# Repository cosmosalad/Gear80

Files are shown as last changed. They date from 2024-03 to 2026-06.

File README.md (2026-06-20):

[▶ Check Out GearSeries](https://github.com/cosmosalad/GearSeries)<br/>
[자작 과정(kr)](https://blog.naver.com/cosmosalad/223262540878)<br/><br/>

# Gear80<br/>
Gear80 is a 80% keyboard based on the rp2040.

<br/>

- gear80_wkl_Aluminum (CNC, Bead blasting-100 mesh + Anodizing-Black-Matte)

<p align="center">
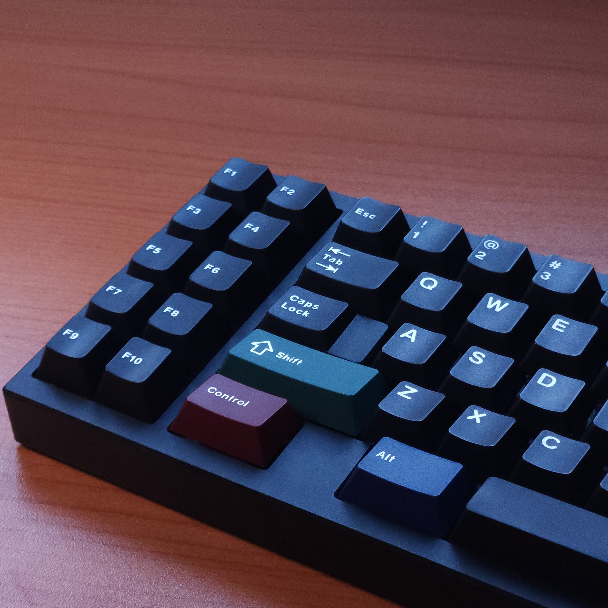
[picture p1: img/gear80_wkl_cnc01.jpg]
    
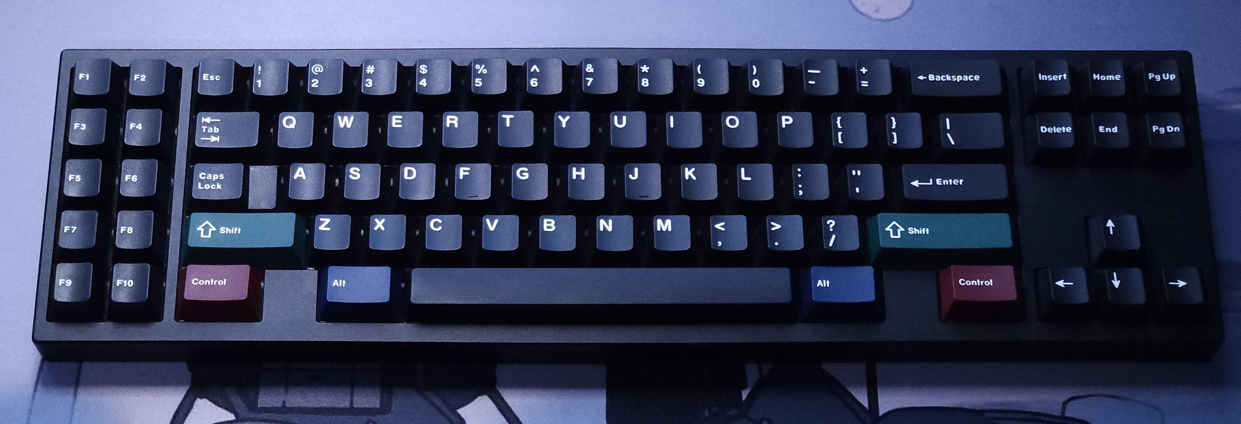
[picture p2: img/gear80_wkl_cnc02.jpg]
  

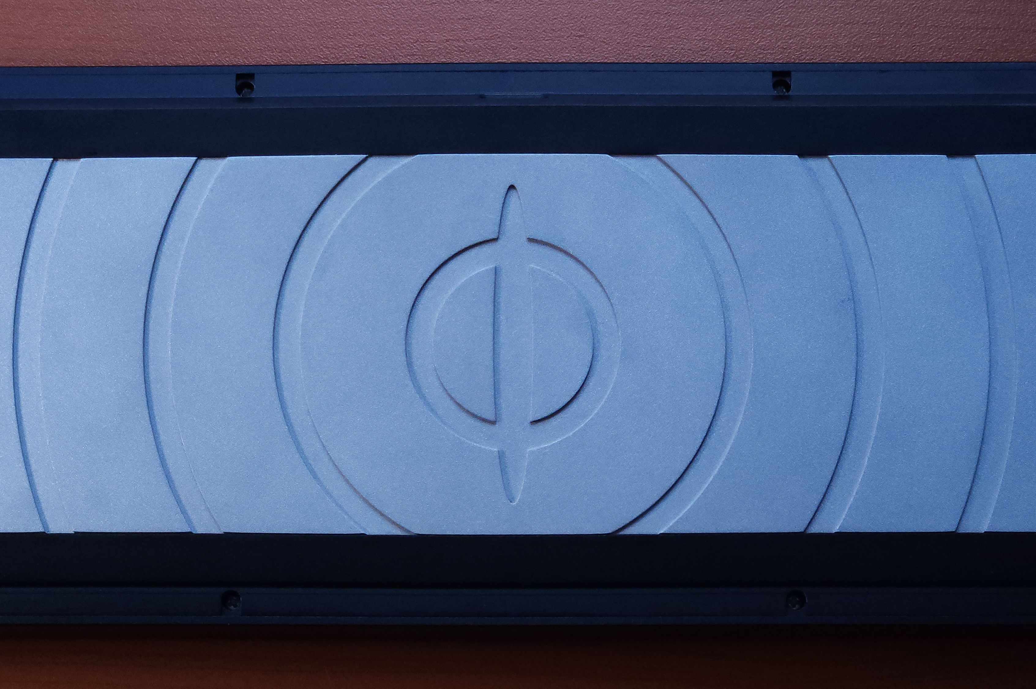
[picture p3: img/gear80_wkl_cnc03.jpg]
    
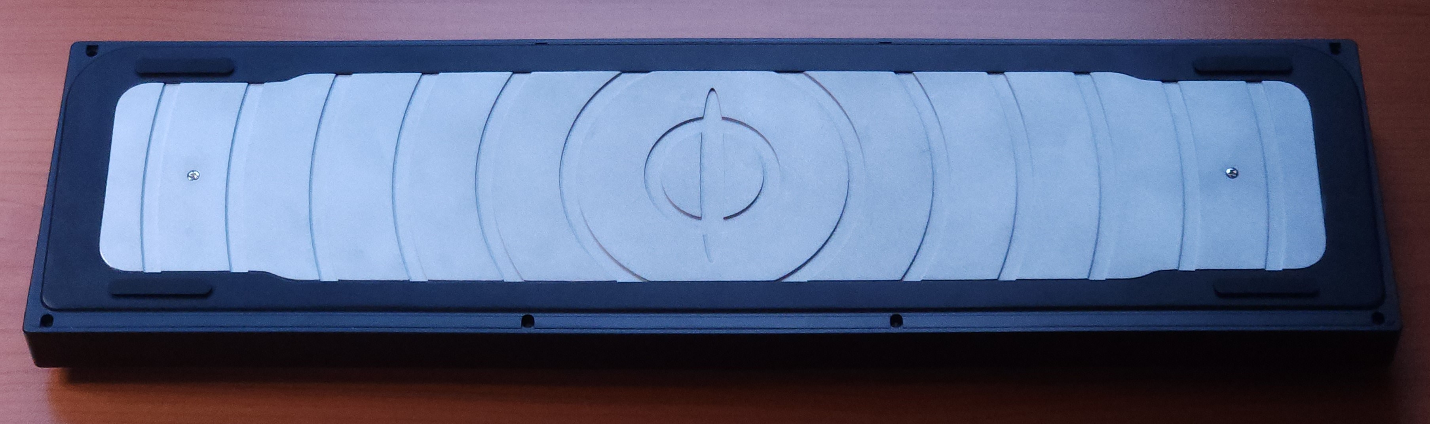
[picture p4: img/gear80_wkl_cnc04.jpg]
  

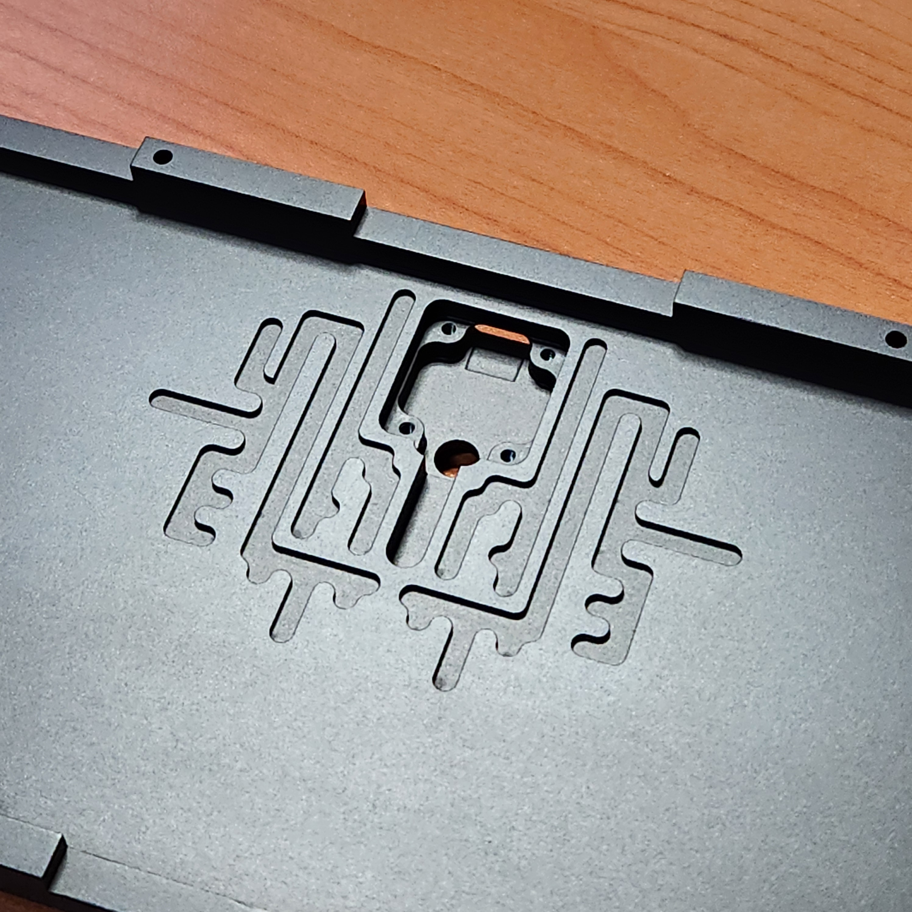
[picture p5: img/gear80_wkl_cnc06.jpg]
    
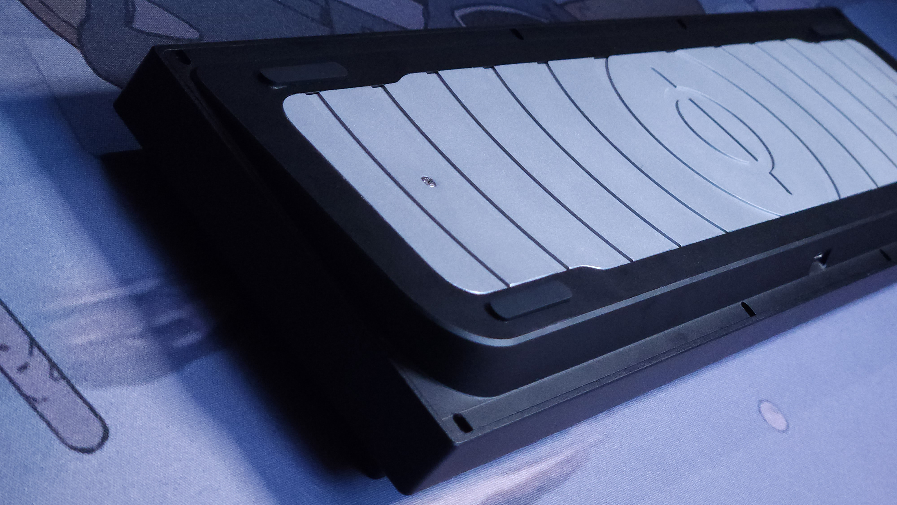
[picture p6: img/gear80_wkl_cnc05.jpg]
  
</p>

<br/>

- gear80_wkl (sla print)

<p align="center">
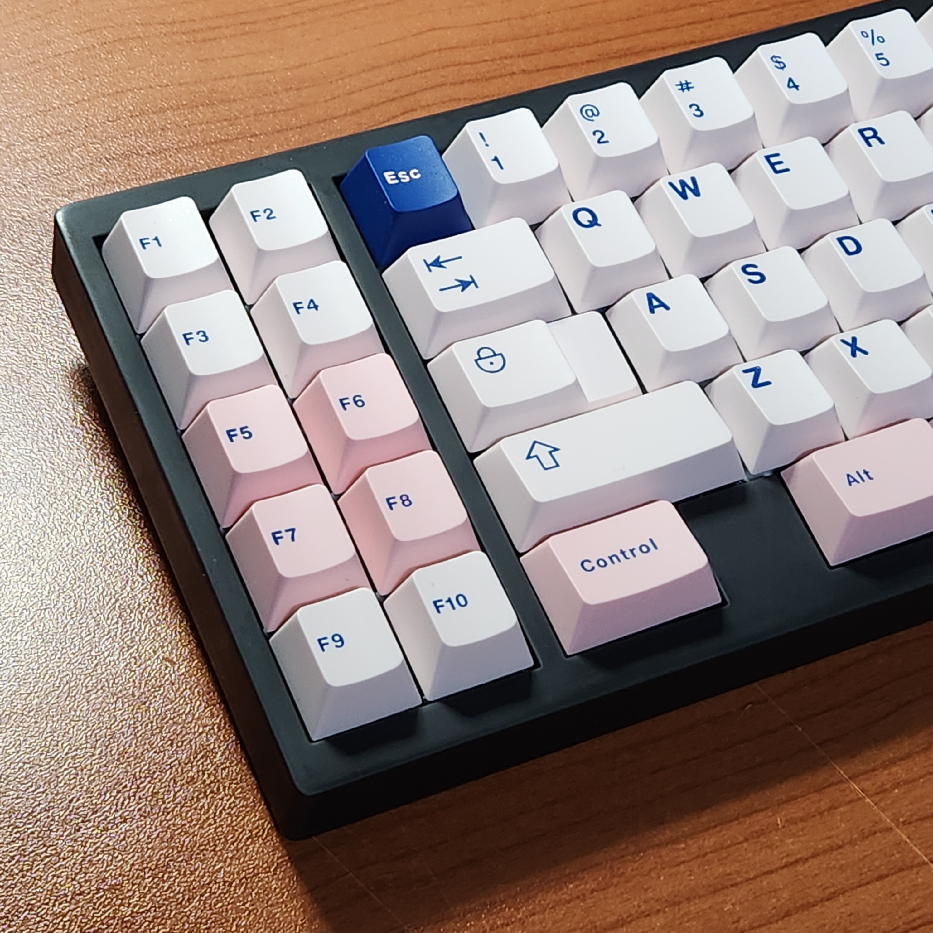
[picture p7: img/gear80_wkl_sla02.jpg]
    
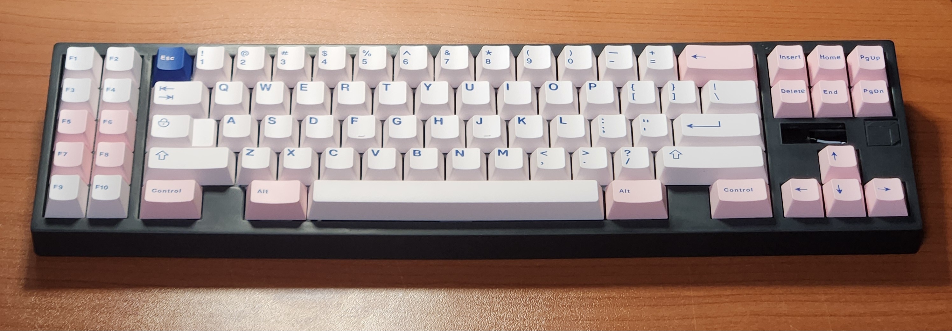
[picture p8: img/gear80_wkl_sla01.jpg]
  
</p>

<br/>

- Gear80-A_1.0mm (sla print)

<p align="center">
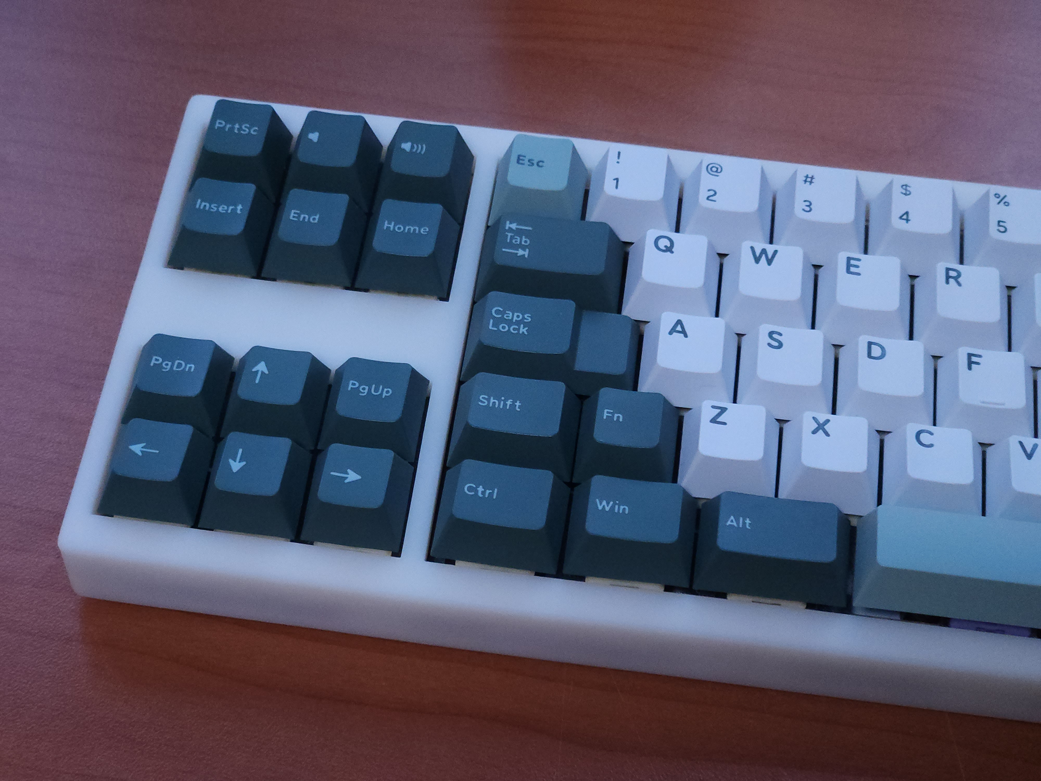
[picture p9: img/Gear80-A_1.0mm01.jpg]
    
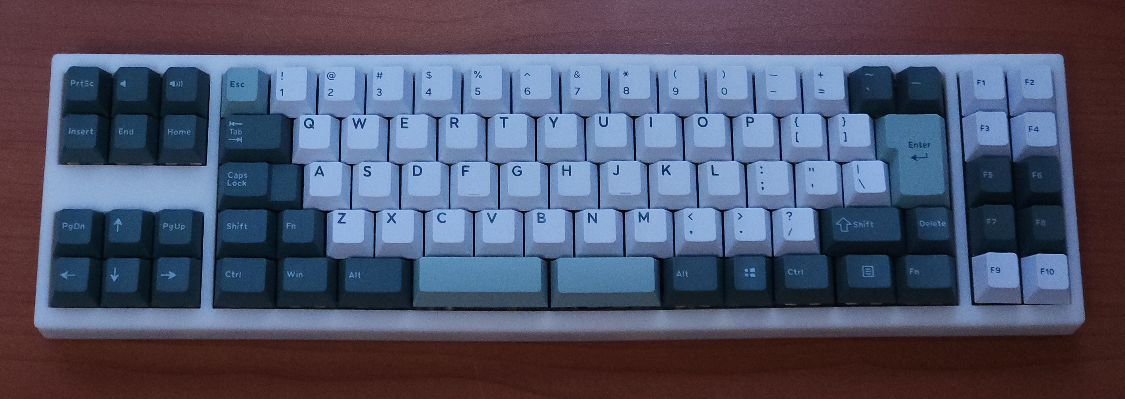
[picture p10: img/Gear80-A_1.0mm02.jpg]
  
</p>

<br/><br/>

## Layout<br/>

- gear80 hotswap, solder
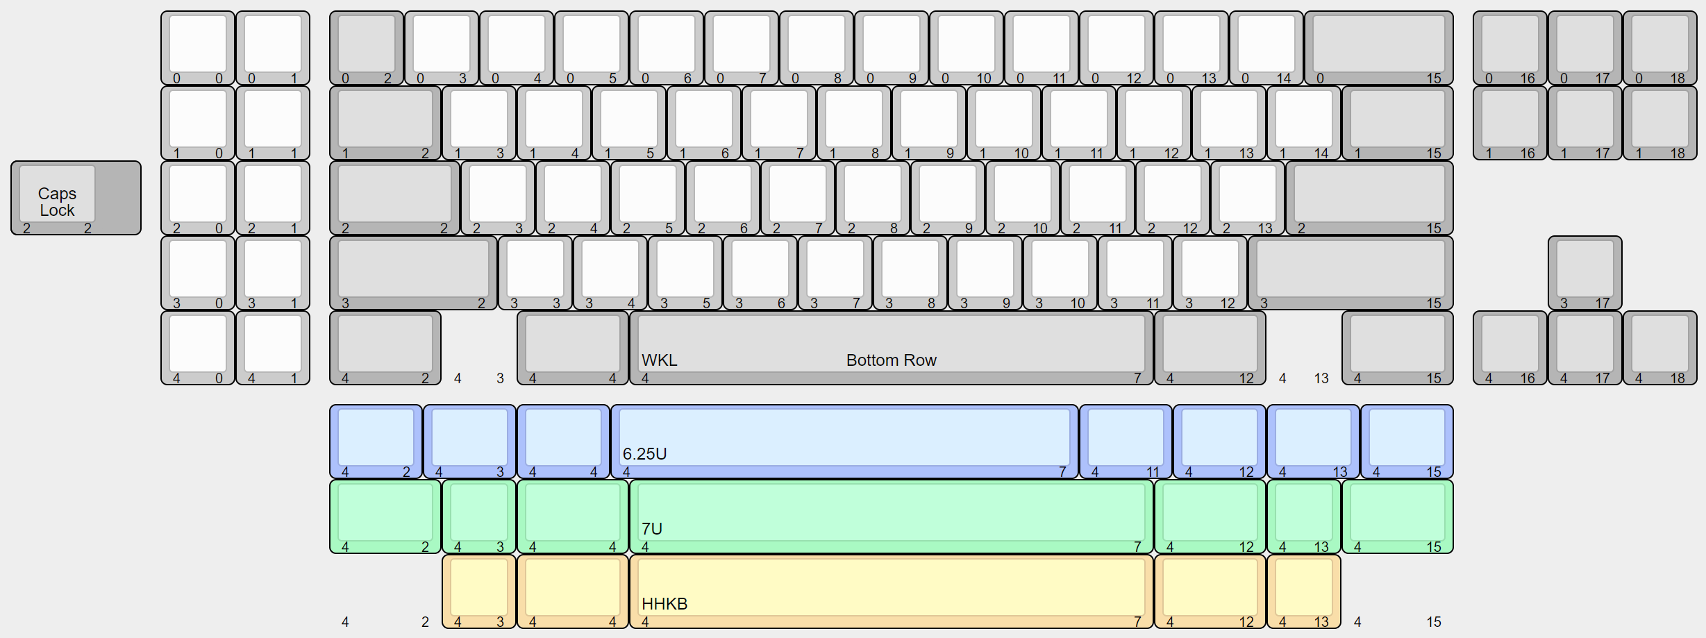
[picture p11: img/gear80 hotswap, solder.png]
gear80 hotswap, solder

<br/>
<br/>

- gear80-a solder
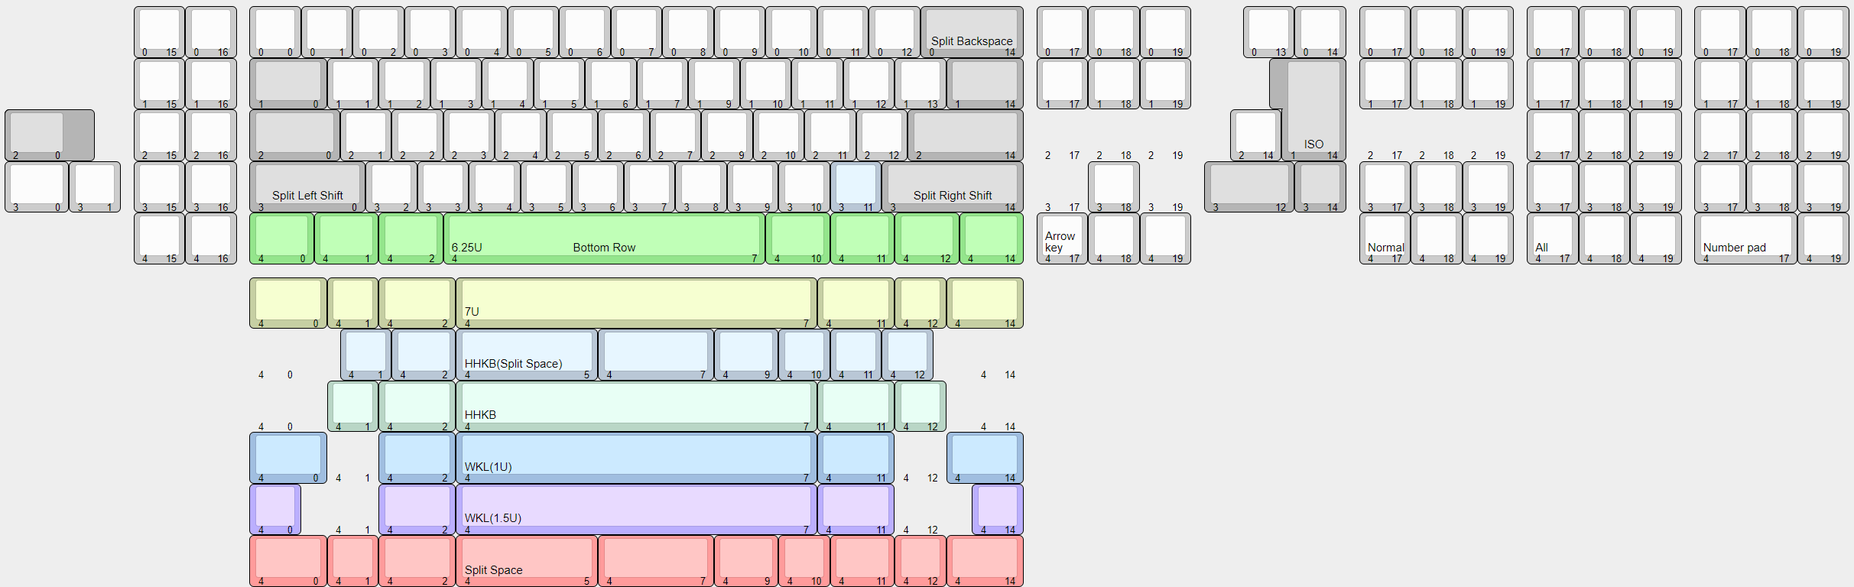
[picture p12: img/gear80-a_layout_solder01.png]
gear80-a solder01
<br/>
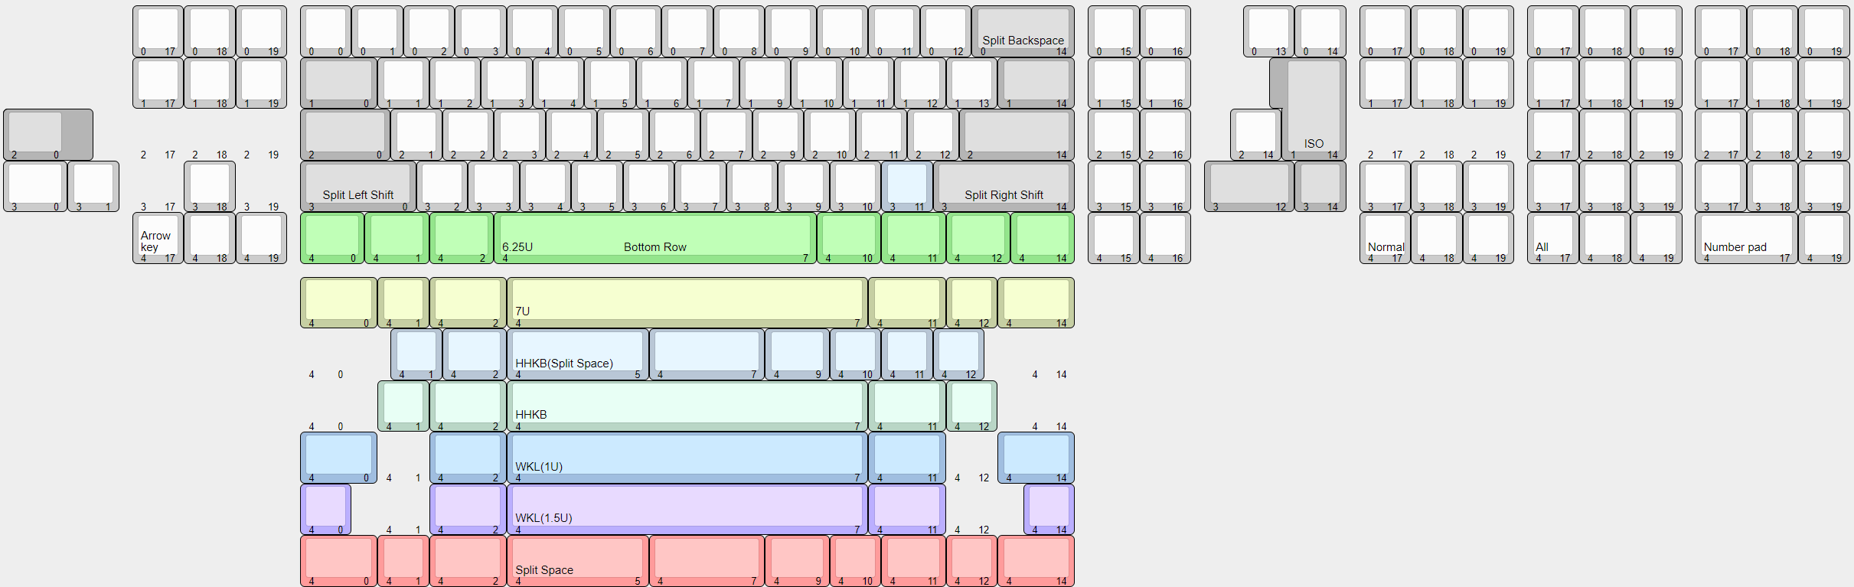
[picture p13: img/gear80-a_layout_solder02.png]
gear80-a solder02
<br/>

<br/>

There is also a [keyboard plate](https://github.com/cosmosalad/Gear80/tree/main/plate).<br/>
[Keyboard case](https://github.com/cosmosalad/Gear80/tree/main/case) corresponding to this layout.<br/>

<br/><br/>

## PCB<br/>
It may differ from the sample photo and file.<br/>
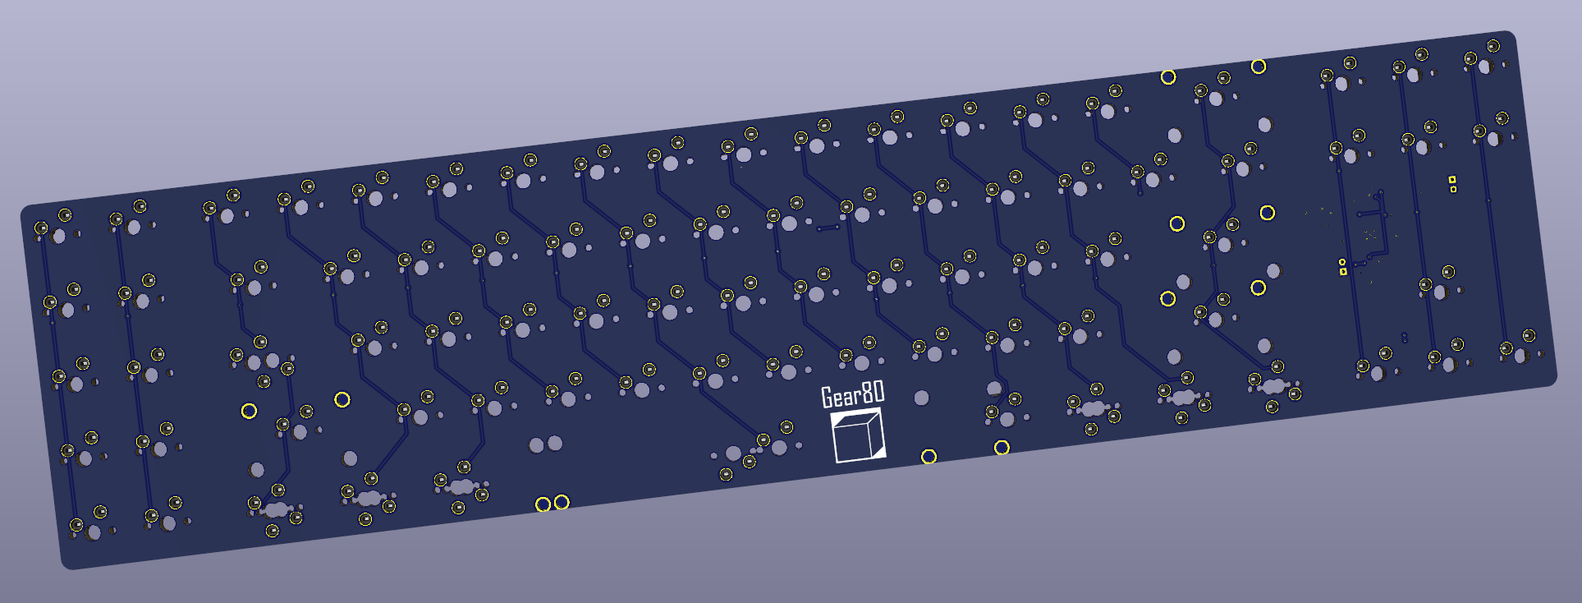
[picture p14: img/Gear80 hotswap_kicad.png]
Gear80 hotswap_kicad
<br/>
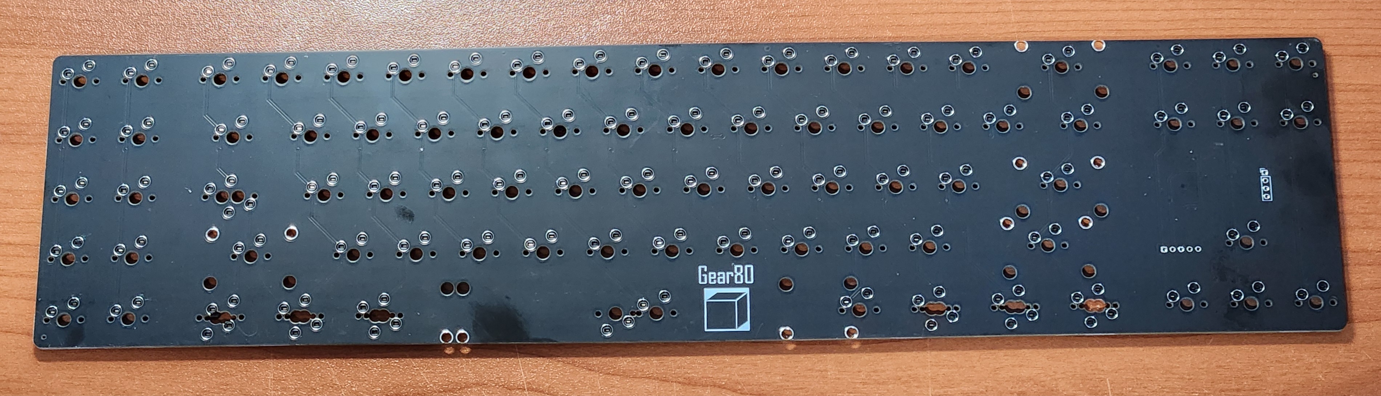
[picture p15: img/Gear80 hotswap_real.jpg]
Gear80 hotswap_real
<br/>

<br/>

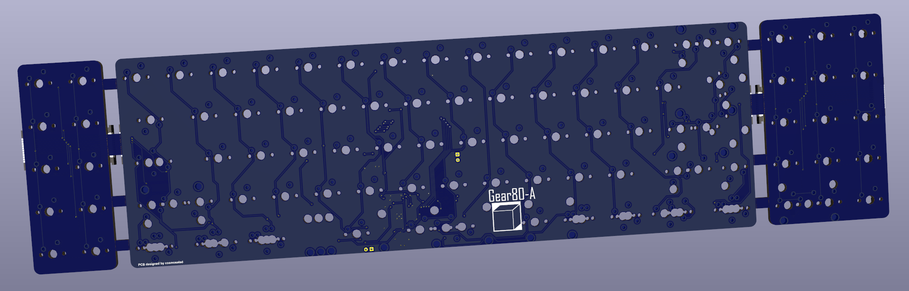
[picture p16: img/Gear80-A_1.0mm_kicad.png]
Gear80-A_1.0mm_kicad
<br/>
Gear80-A_1 0mm_real<br/>
[More pcb ](https://github.com/cosmosalad/Gear80/tree/main/pcb)<br/>

This pcb was made by jlcpcb.(list of pcb parts [main](https://github.com/cosmosalad/Gear80/blob/main/pcb/Gear80%20solder/part%20list.md), [daughterboard](https://github.com/cosmosalad/Gear80/blob/main/pcb/daughterboard/part%20list.md/))<br/><br/>

This pcb prepared the [vial](https://github.com/cosmosalad/Gear80/tree/main/vial) as firmware<br/><br/><br/>

## typing sound<br/>
<p align="center">

  <a href="https://youtube.com/embed/aFRDwg6jCEE?feature=shared">
    gear80_full foam
  </a><br/>
Gear80 / Aluminum / HMX Hyacinth v2u / PC Plate / ABS / Full foam
<br/><br/>

  <a href="https://youtube.com/embed/MRHb9Hr9hBU?feature=shared">
    gear80_no foam
  </a><br/>
Gear80 / Aluminum / HMX Garnet / PC Plate / ABS / no foam
<br/><br/>
  
  <a href="https://youtube.com/embed/lhAkio-YmMc?feature=shared">
    gear80_no foam
  </a><br/>
Gear80 Lite / Bsun RAW /  PC Plate / ABS / Full foam
<br/><br/>
  
  <a href="https://youtube.com/embed/d4M2H16-_T0?feature=shared">
    gear80-A_full foam
  </a><br/>
Gear80-A / sla / HMX Cheese / PC Plate / PBT / Full foam
<br/><br/>

</p>
<br/>

## Reference<br/>
- [Gear60](https://github.com/cosmosalad/Gear60)
<br/>

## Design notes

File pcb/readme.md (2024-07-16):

### Gear80 hotswap<br/>
Gear80 hotswap01<br/>
Gear80 hotswap02<br/>

<br/><br/>

### Gear80 solder<br/>
Gear80 solder01<br/>
Gear80 solder02<br/>

<br/><br/>

### Gear80-A_1.0mm<br/>
Gear80-A_1 0mm01<br/>
Gear80-A_1 0mm02<br/>

<br/><br/>

### Gear80-A_0.5mm<br/>
Gear80-A_0 5mm01<br/>
Gear80-A_0 5mm02<br/>

<br/><br/>

### Gear80-daughterboard ver.0.1, ver.0.2<br/>
daughterboard<br/>
daughterboard_ver0 2<br/>

<br/><br/>

### Gear80 hotswap flex cut<br/>
gear80_hotswap_flex_cut01<br/>
gear80_hotswap_flex_cut02<br/>

<br/><br/>

### Gear85 hotswap flex cut, number pad<br/>
gear85_hotswap_flex_cut01<br/>
gear85_hotswap_flex_cut02<br/>

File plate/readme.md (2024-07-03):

### gear80_plate<br/>
gear80_plate<br/>

<br/><br/><br/>

### gear80-a_plate<br/>
gear80-a_plate<br/>

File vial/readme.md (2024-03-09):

Hold the boot button and connect usb.<br/>

usb<br/>
After connecting to the keyboard, add the [uf2 file]https://github.com/cosmosalad/Gear80/tree/main/vial).<br/><br/><br/>

Open the [vial](https://vial.rocks/).<br/>

<br/>

- gear80_vial.uf2<br/>
<br/>

<br/>

- gear80-a_vial.uf2<br/>
<br/>

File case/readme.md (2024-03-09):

### gear80_top_wkl_sla<br/>
gear80_top_wkl

<br/><br/><br/><br/>

### gear80_top_sla<br/>
gear80_top

<br/><br/><br/><br/>

### gear80_bottom_sla<br/>
gear80_bottom

<br/><br/><br/><br/>

### gear80_top_cnc<br/>
gear80_top_wkl_cnc

<br/><br/><br/><br/>

### gear80_bottom_cnc, bottom_part01_cnc<br/>
gear80_bottom_cnc
sasd

<br/><br/><br/><br/>

### gear80_bottom_normal<br/>
normal

<br/><br/><br/><br/>

### sla_part(top_wkl_sla, top_sla)<br/>
part

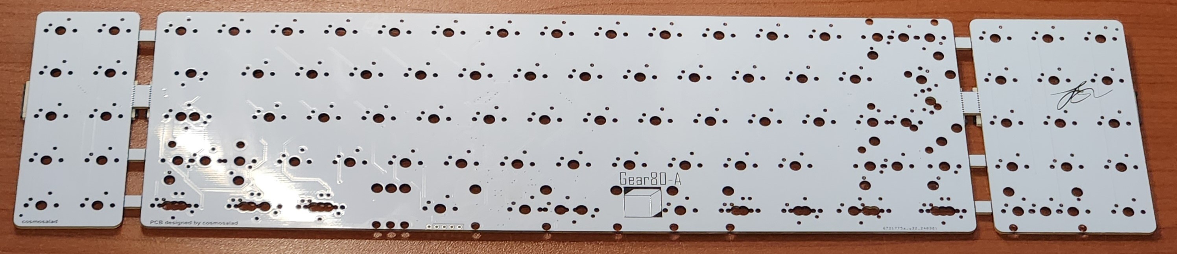
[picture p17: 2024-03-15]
img/Gear80-A_1.0mm_real.jpg

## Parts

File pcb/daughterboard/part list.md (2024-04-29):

| **Comment** | **Designator** | **Footprint** | **JLCPCB Part #** |
|:---:|:---:|:---:|:---:|
| USB_C_Receptacle_USB2.0 | J2 | Connector_USB:USB_C_Receptacle_HRO_TYPE-C-31-M-12 | C165948 |
| MF-MSMF050-2 500mA | F1 | Fuse:Fuse_2010_5025Metric | C17313 |
| 5.1k | R1,R2 | Resistor_SMD:R_0402_1005Metric | C25905 |
| Conn_01x04 | J1 | Connector_JST:JST_SH_SM04B-SRSS-TB_1x04-1MP_P1.00mm_Horizontal | C2845363 |
| SRV05-4 | U1 | PCM_marbastlib-various:SOT-23-6-routable | C7420376 |

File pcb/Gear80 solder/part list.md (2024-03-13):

|  **Comment**  | **Designator** | **Footprint** | **JLCPCB Part #** |
|:---:|:---:|:---:|:---:|
| D_Small | ALL D | Diode_SMD:D_SOD-123 | C2099 |
| 1uF | C1,C5,C12,C15,C16 | CAP-SMD_BD5.0-L5.3-W5.3-LS6.3-FD | C15684 |
| 10uF | C4 | Capacitor_SMD:C_0603_1608Metric | C19702 |
| 100nF | C2,C3,C6,C7,C8,C9,C10,C11 | Capacitor_SMD:C_0402_1005Metric | C1525 |
| 22pF | C13,C14 | Capacitor_SMD:C_0402_1005Metric | C147430 |
| 27Ω | R1,R2 | Resistor_SMD:R_0402_1005Metric | C138021 |
| 1k | R5,R9 | Resistor_SMD:R_0402_1005Metric | C11702 |
| 5.1k | R6,R7,R8 | Resistor_SMD:R_0402_1005Metric | C25905 |
| RP2040 | U1 | Package_DFN_QFN:QFN-56-1EP_7x7mm_P0.4mm_EP3.2x3.2mm | C2040 |
| XC6206P332MR  | U4 | Package_TO_SOT_SMD:SOT-23-3 | C5446 |
| X322512MSB4SI | Y1 | Crystal:Crystal_SMD_3225-4Pin_3.2x2.5mm | C9002 |
| W25Q128JVSIQ  | U3 | Package_SO:SOIC-8_5.23x5.23mm_P1.27mm | C97521 |
| Conn_01x04 | J3 | Connector_JST:JST_SH_SM04B-SRSS-TB_1x04-1MP_P1.00mm_Horizontal | C2845363 |

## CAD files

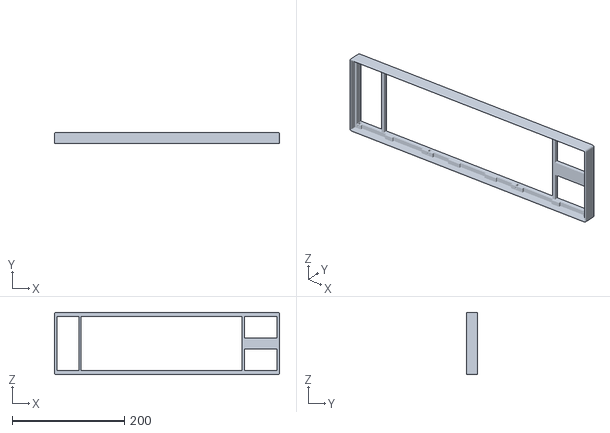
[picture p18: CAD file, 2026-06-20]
case/gear80-A_top.stl
400.5 x 19.0 x 111.2

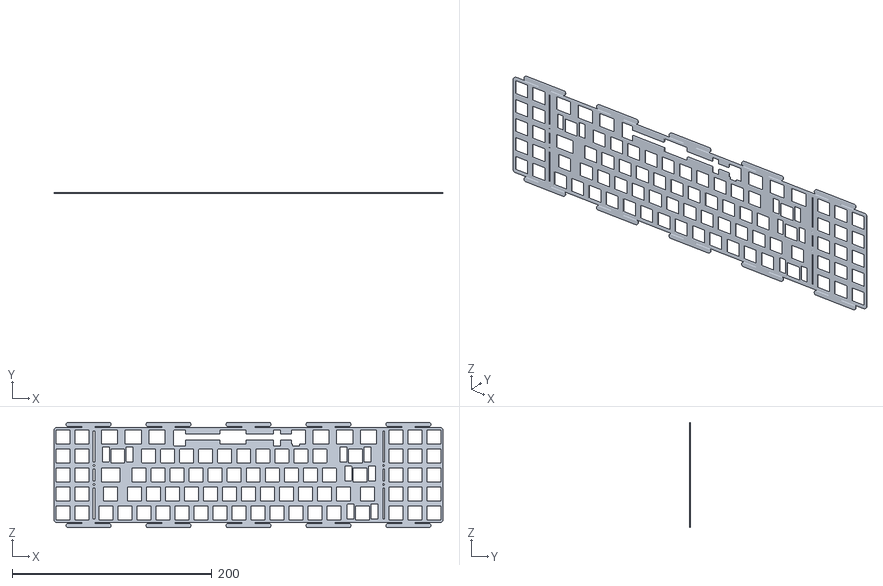
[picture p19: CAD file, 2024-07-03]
plate/gear80_plate.stl
389.7 x 1.50 x 105.2

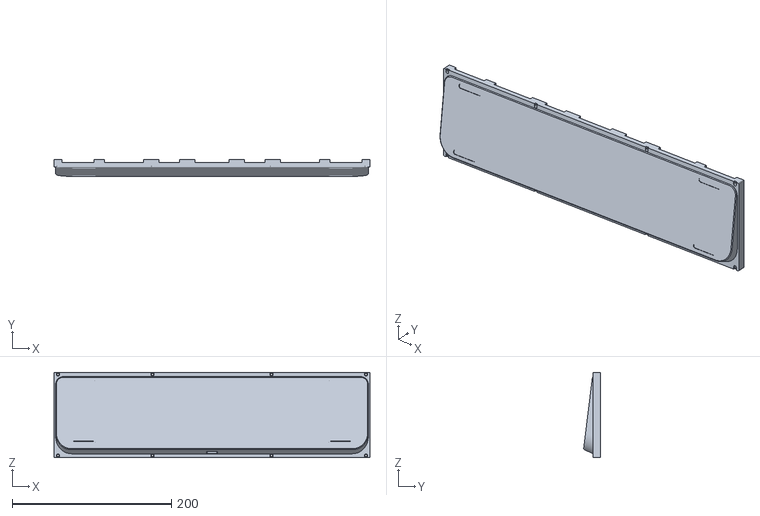
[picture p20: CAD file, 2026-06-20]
case/gear80-A_bottom.stl
396.5 x 21.0 x 107.2

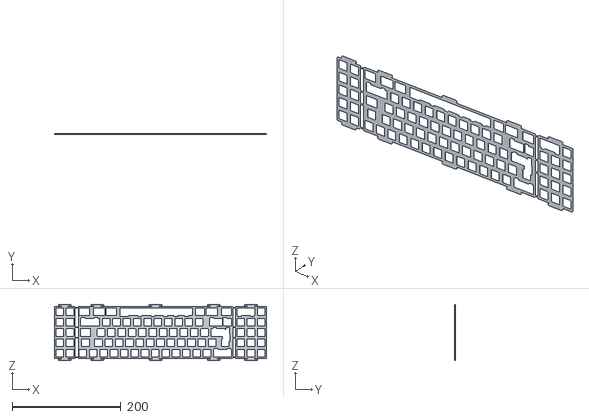
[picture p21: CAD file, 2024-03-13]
plate/gear80-a_plate.stl
390.5 x 1.50 x 103.2

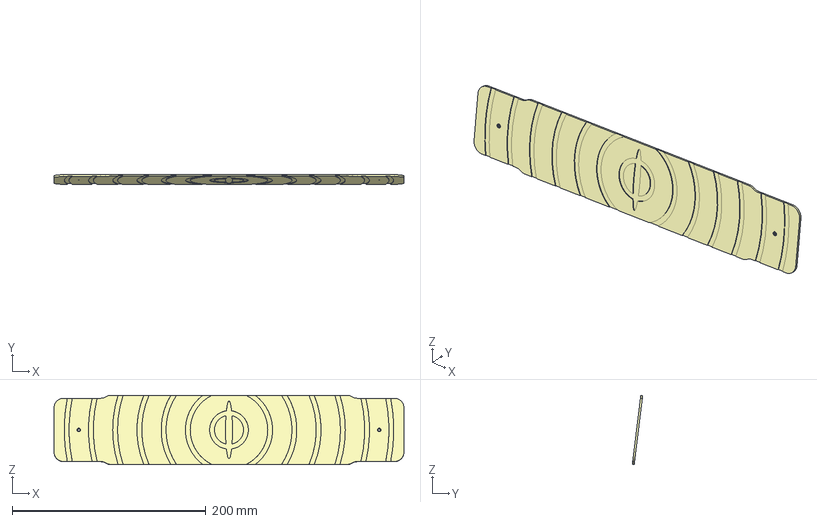
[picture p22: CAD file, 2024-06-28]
case/bottom_part01_cnc.step
361.1 x 10.7 x 71.4 mm

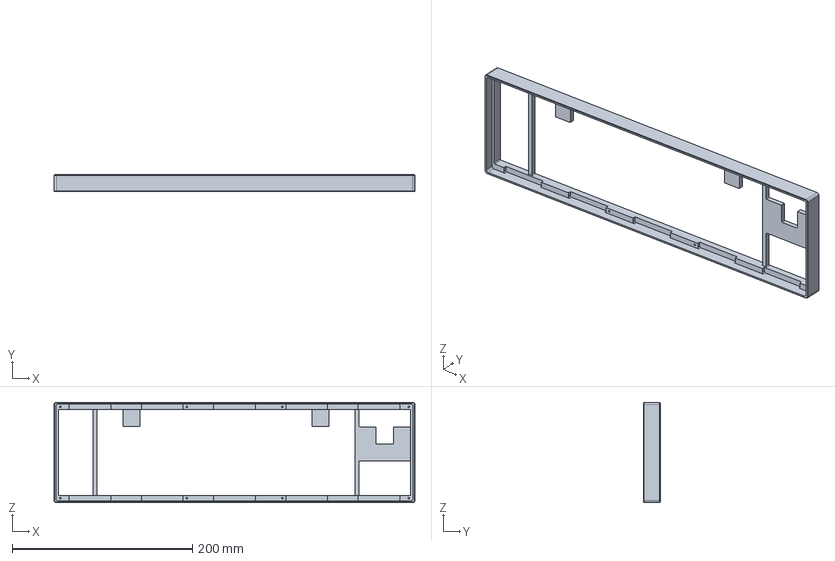
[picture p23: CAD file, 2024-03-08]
case/gear80_top_wkl_cnc.step
400.5 x 19.0 x 111.3 mm

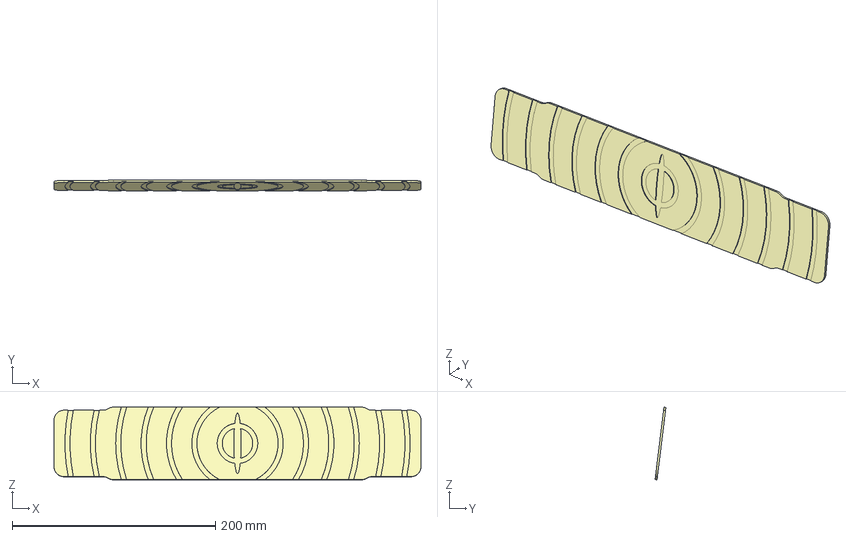
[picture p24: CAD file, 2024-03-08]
case/gear80_bottom_part01_cnc.step
361.5 x 10.7 x 71.6 mm

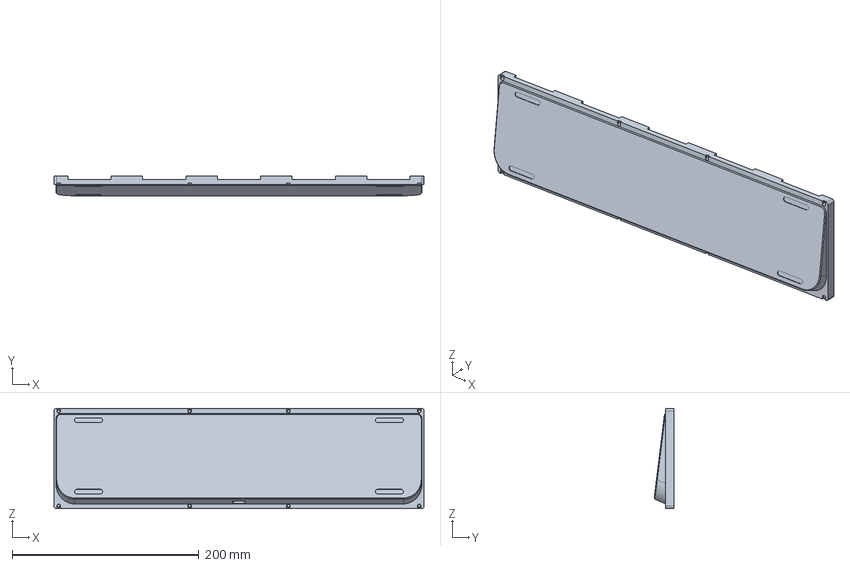
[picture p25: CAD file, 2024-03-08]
case/gear80_bottom_normal_cnc.step
396.5 x 21.0 x 107.2 mm

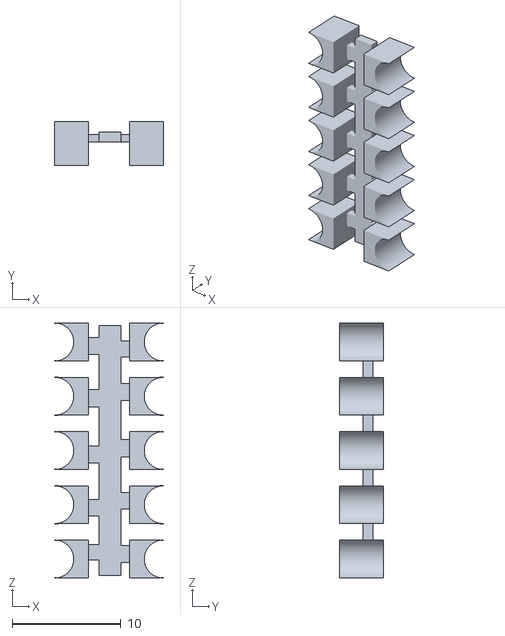
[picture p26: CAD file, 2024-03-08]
case/sla_part.stl
10.0 x 4.10 x 23.5

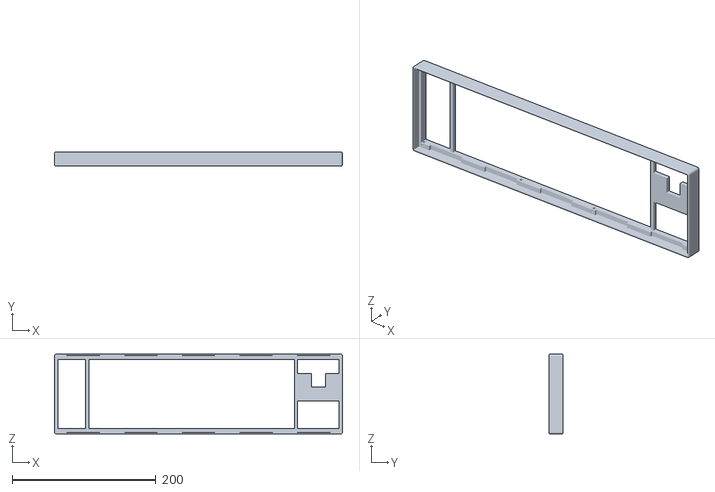
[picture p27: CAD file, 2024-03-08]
case/gear80_top_sla.stl
400.5 x 19.0 x 111.2

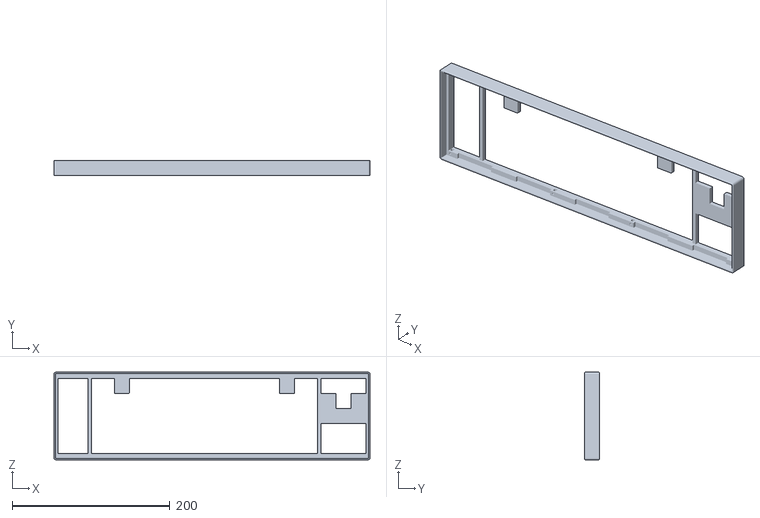
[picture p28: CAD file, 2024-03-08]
case/gear80_top_wkl_sla.stl
400.5 x 19.0 x 111.2

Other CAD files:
case/gear80_bottom_cnc.step
case/gear80_bottom_sla.stl
plate/gear80-a_plate.dxf
plate/gear80_plate.dxf

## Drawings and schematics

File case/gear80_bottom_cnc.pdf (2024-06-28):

1

A

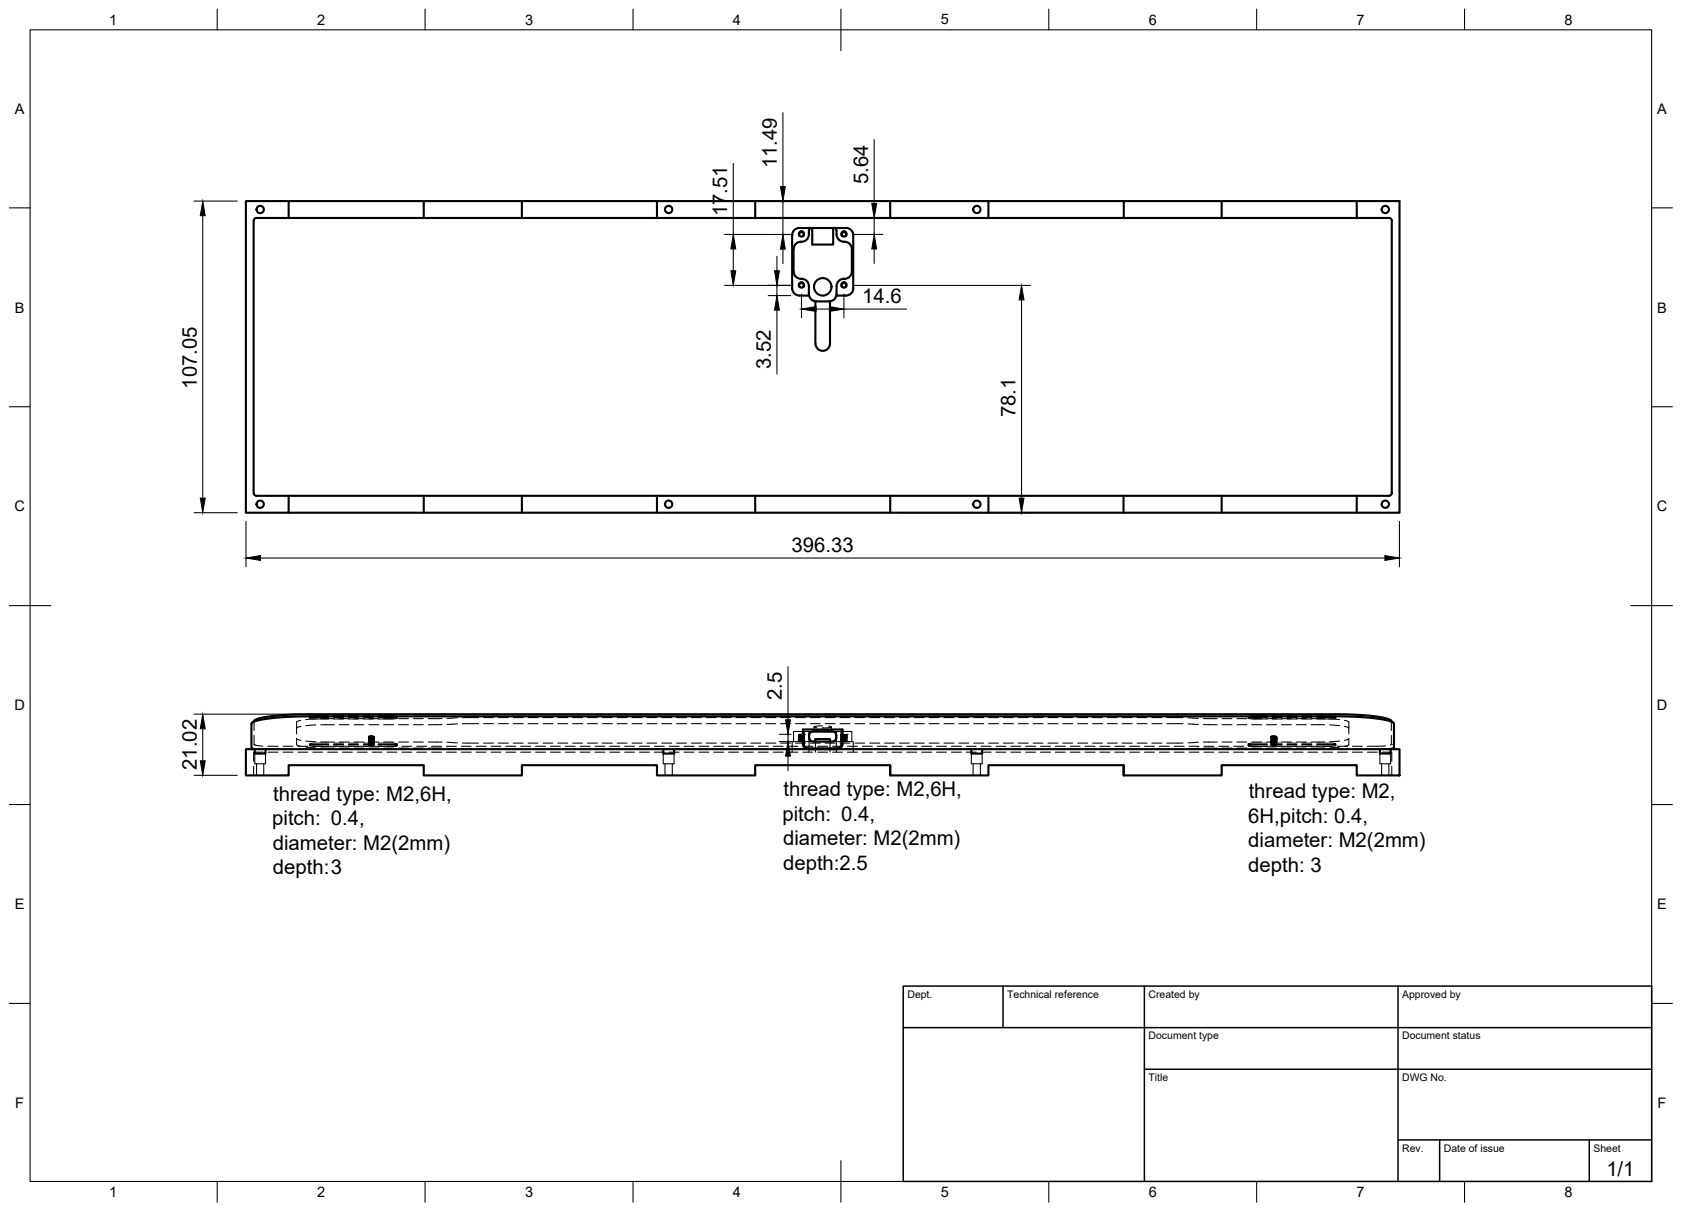
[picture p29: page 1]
Dept.; Technical reference; Created by; Approved by; Document type; Document status; Title; DWG No.; Rev.; Date of issue; Sheet; 396.33 ¹⁰⁷.05 21.02; thread type: M2,6H, pitch: 0.4, diameter: M2(2mm); depth:2.5 ².5; thread type: M2,6H, pitch: 0.4, diameter: M2(2mm) depth:3; thread type: M2, 6H,pitch: 0.4, diameter: M2(2mm) depth: 3

1

A

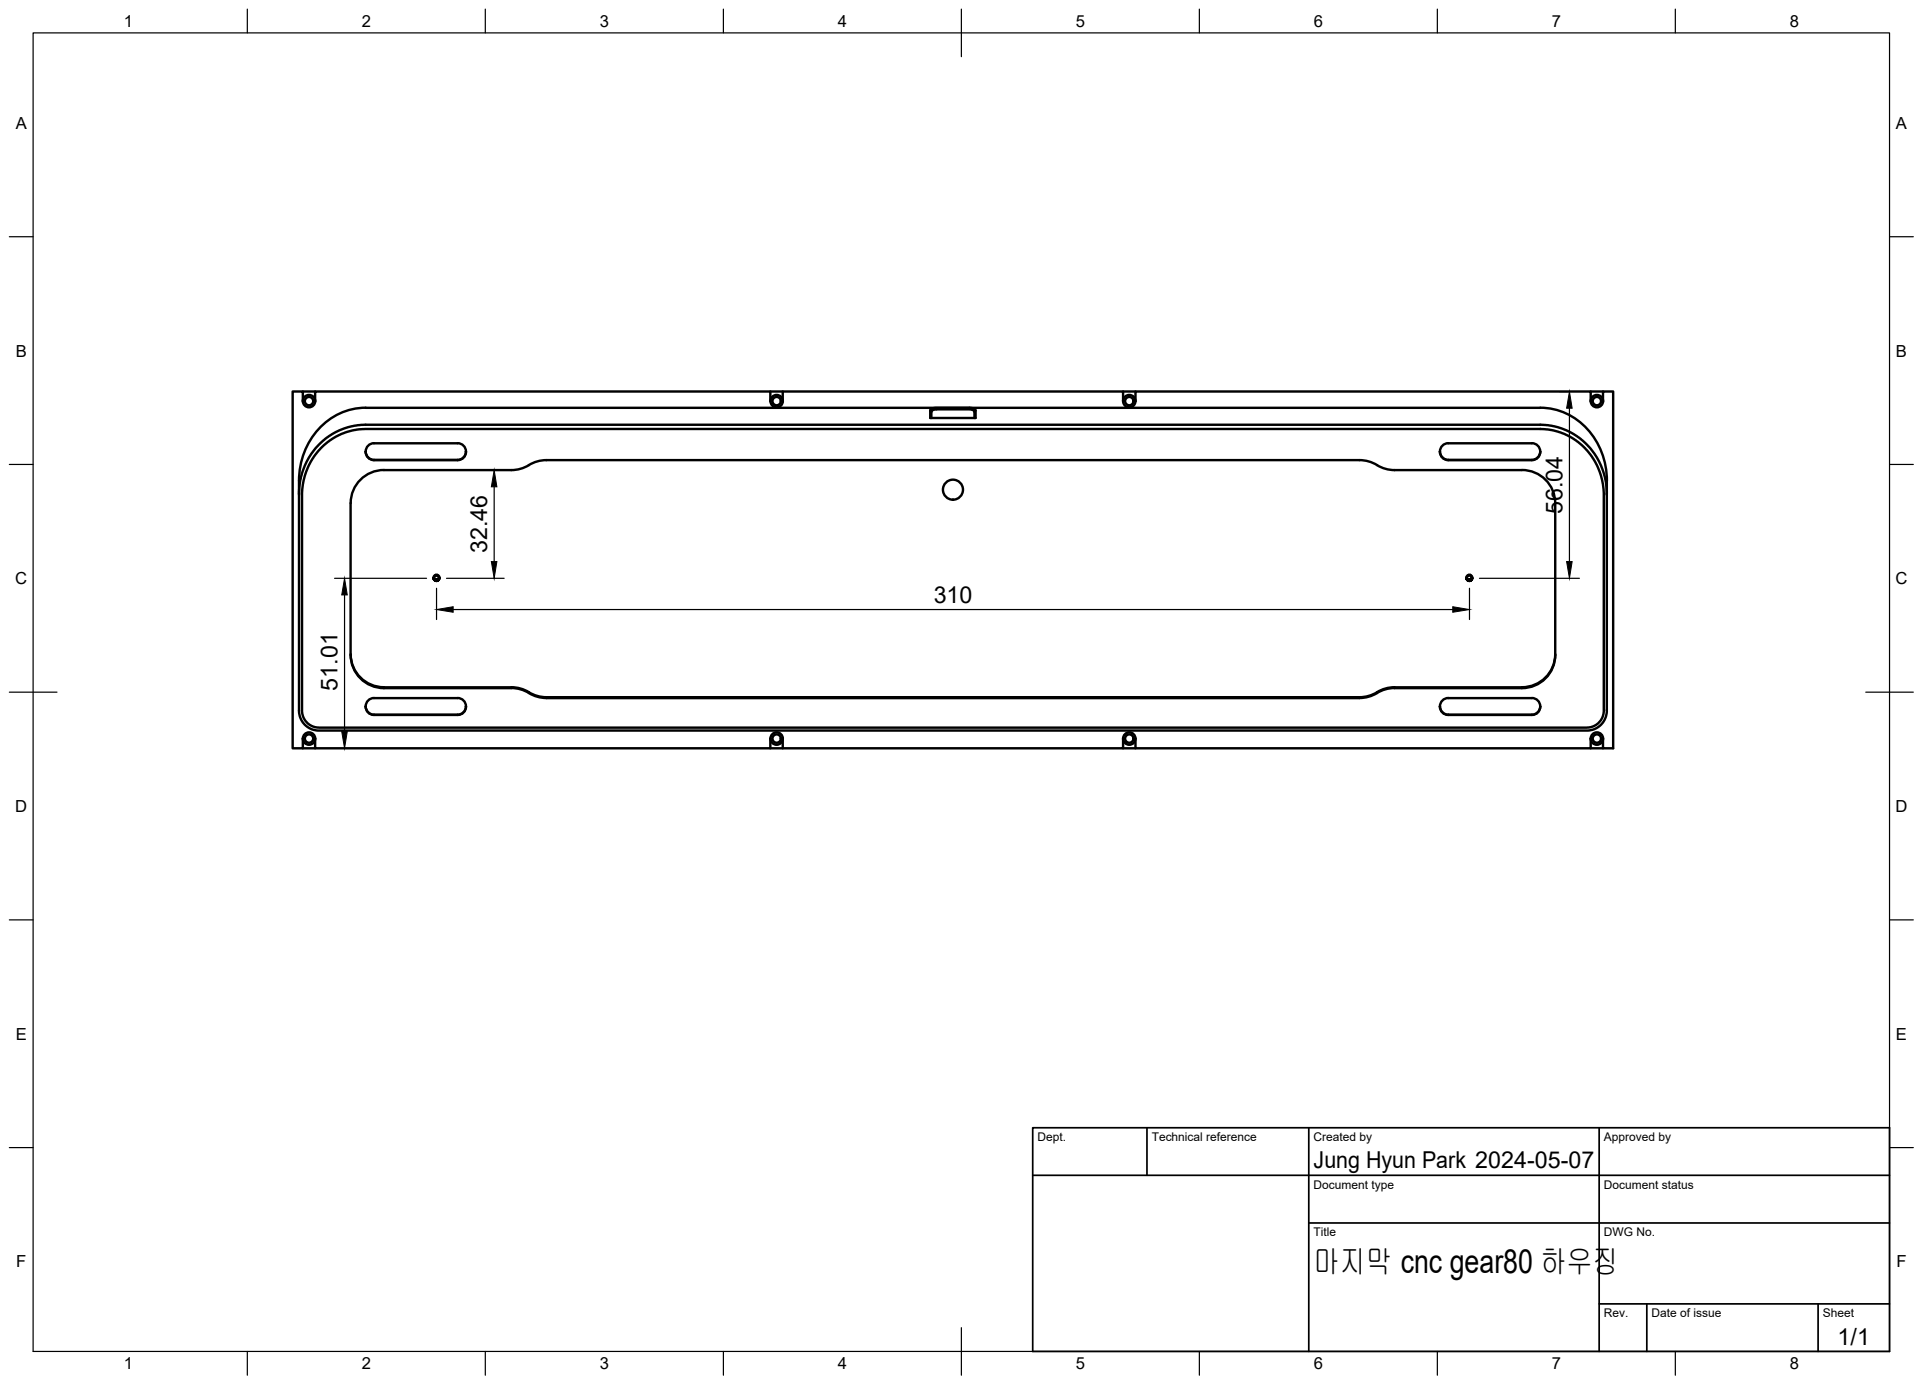
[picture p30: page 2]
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

Jung Hyun Park

마지막 cnc gear80 하우징

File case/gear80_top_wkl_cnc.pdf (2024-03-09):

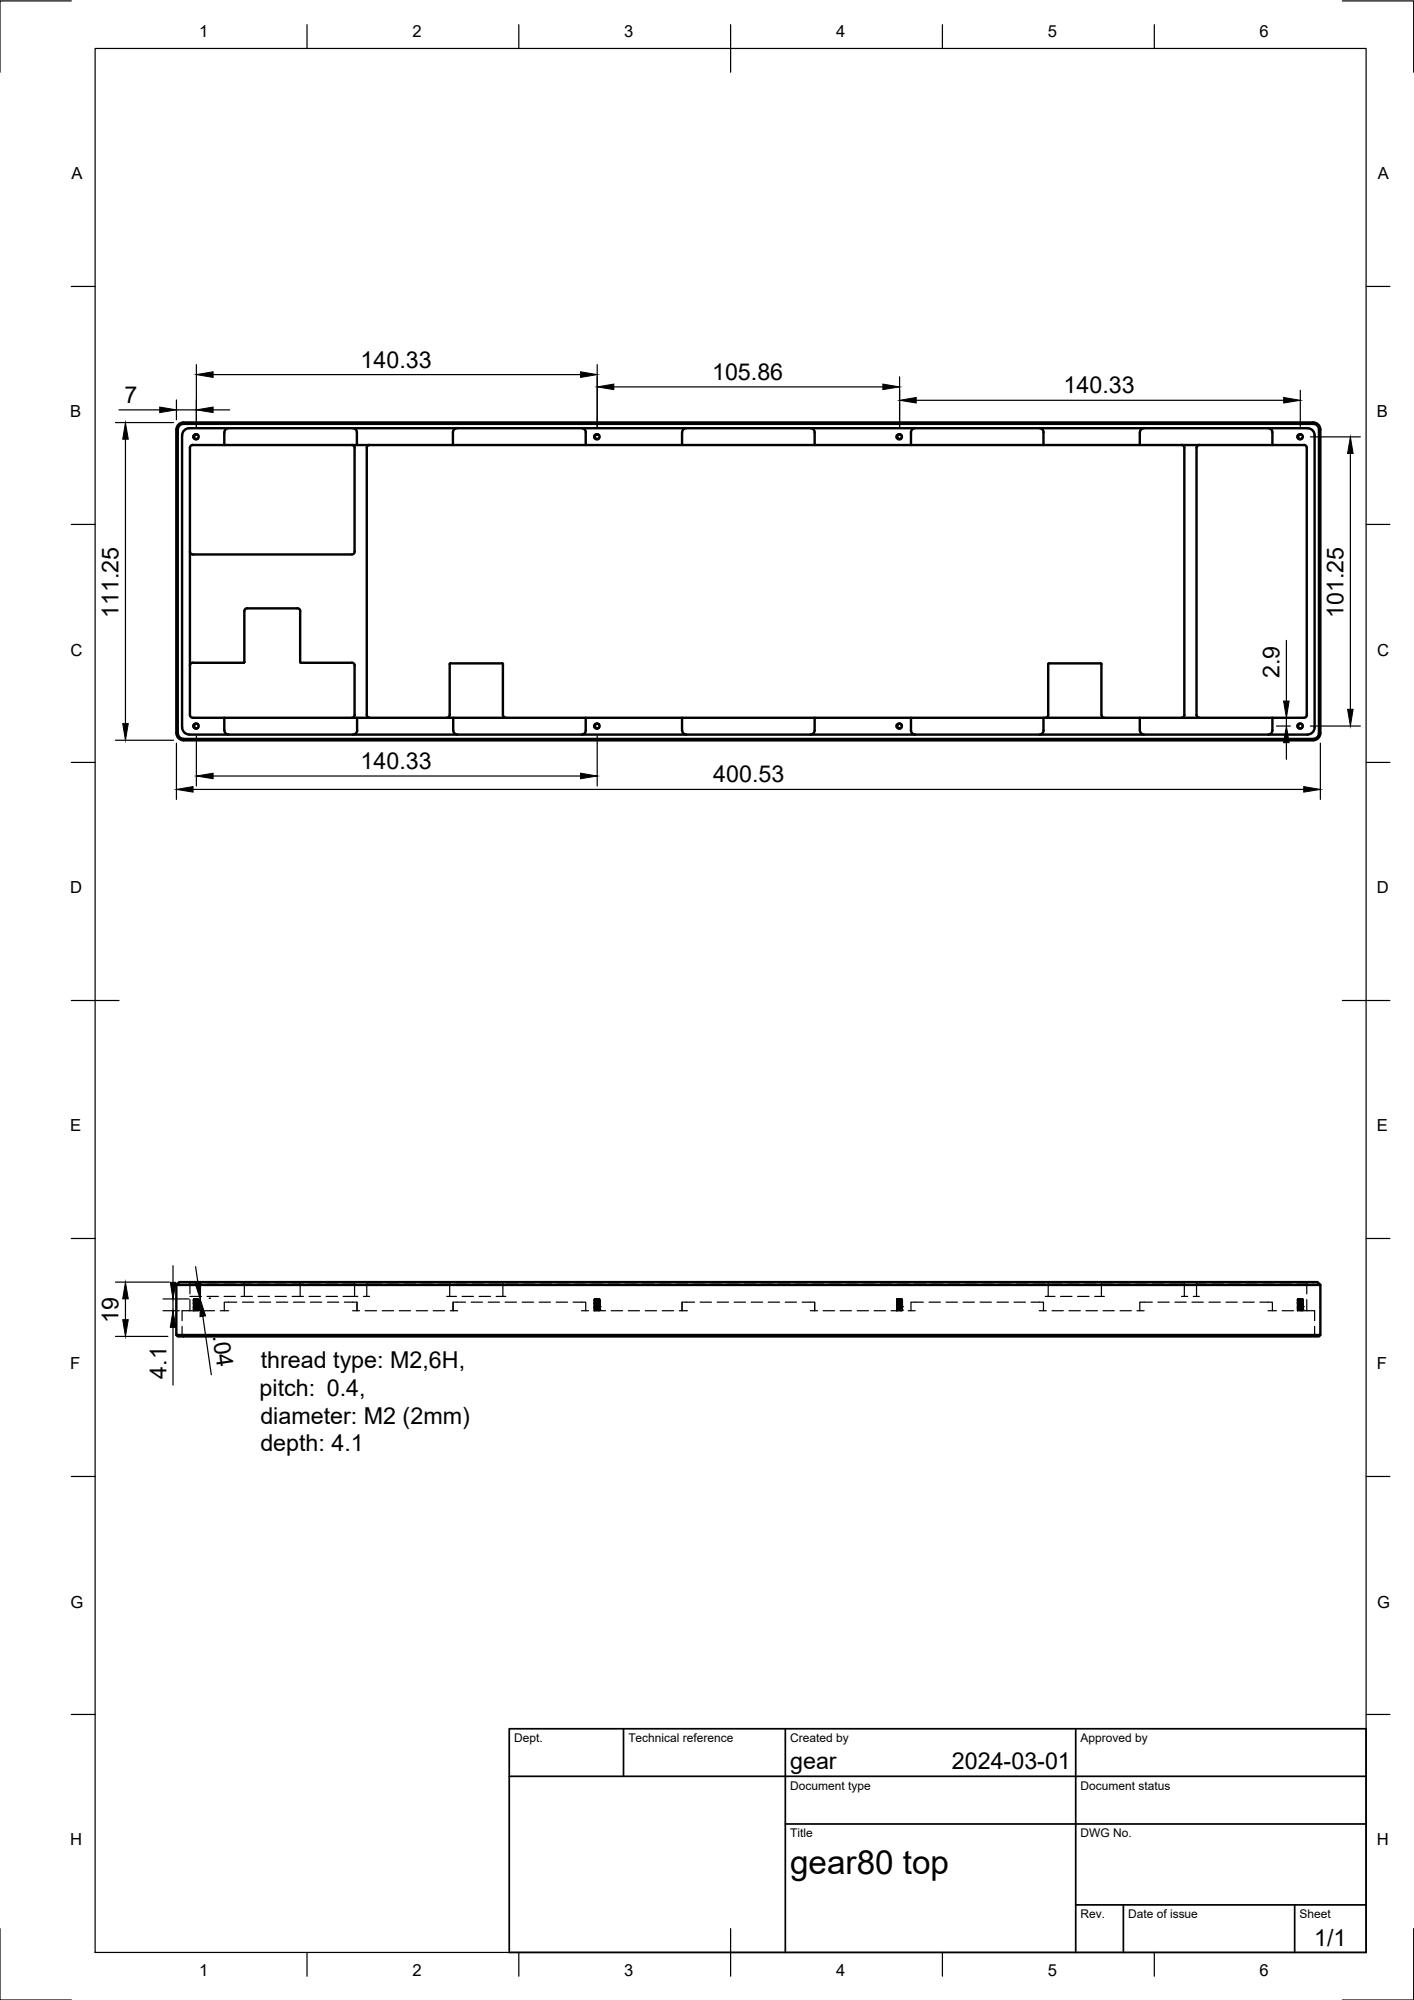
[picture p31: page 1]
thread type: M2,6H, pitch: 0.4, diameter: M2 (2mm) depth: 4.1

Dept. | Technical reference | Created by gear 2024-03-01 | Approved by

Document type | Document status

Title gear80 top | DWG No.

Rev. | Date of issue | Sheet 1/1

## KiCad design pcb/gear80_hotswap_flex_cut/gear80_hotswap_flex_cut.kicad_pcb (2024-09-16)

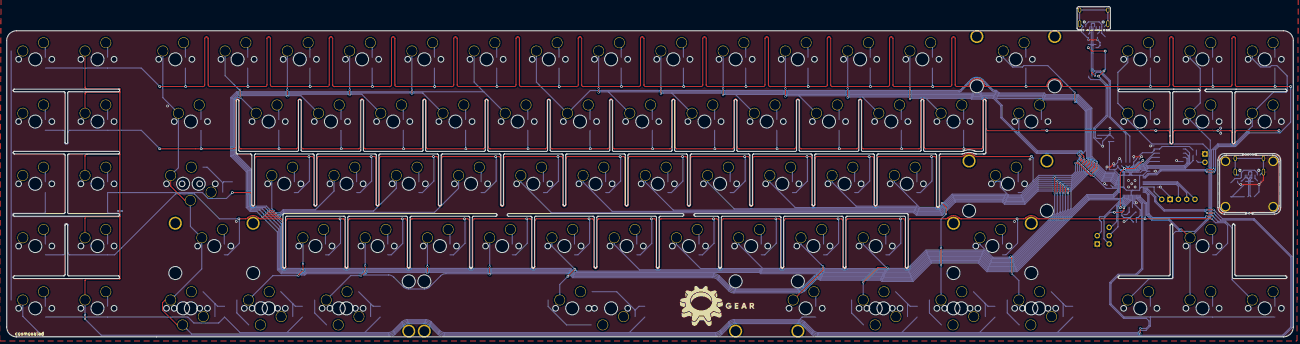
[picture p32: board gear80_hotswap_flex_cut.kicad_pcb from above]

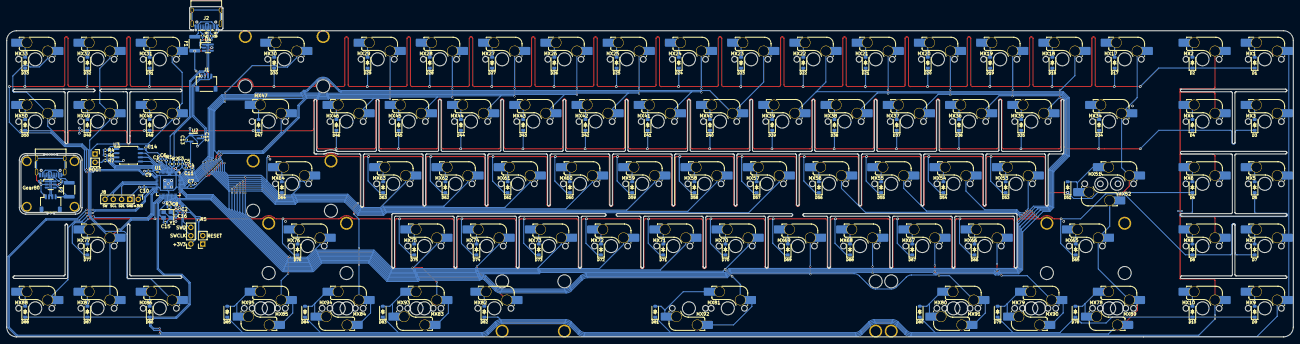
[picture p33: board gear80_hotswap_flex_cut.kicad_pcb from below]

Board: 2 copper layers, 393.7 x 101.0 mm, 220 parts (212 on the bottom side), 140 nets.

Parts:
BOOT1: SW_Push; PinSocket_1x02_P2.54mm_Vertical
C1, C2, C4, C5, C6, C7, C8, C9, C10: 100n; C_0402_1005Metric
C3, C11, C12, C13, C14: 1u; C_0402_1005Metric
C15, C16: 22p; C_0402_1005Metric
D1, D2, D3, D4, D5, D6, D7, D8, D9, D10, D17, D18, D19, D20, D21, D22, D23, D24, D25, D26, D27, D28, D29, D30, D31, D32, D33, D34, D35, D36, D37, D38, D39, D40, D41, D42, D43, D44, D45, D46, D47, D48, D49, D50, D51, D53, D54, D55, D56, D57, D58, D59, D60, D61, D62, D63, D64, D65, D66, D67, D68, D69, D70, D71, D72, D73, D74, D75, D76, D77, D78, D79, D80, D81, D82, D83, D84, D85, D86, D87, D88: D_Small; D_SOD-123_new
F1, F2: MF-MSMF050-2; Fuse_1812_4532Metric
GEAR: LOGO
J1, J4: Conn_01x04; JST_SH_SM04B-SRSS-TB_1x04-1MP_P1.00mm_Horizontal
J2, J5: USB_C_Receptacle_USB2.0; USB_C_Receptacle_HRO_TYPE-C-31-M-12
J3: SWD; PinSocket_1x03_P2.54mm_Vertical
J8: Conn_01x05; PinSocket_1x05_P2.54mm_Vertical
MX1, MX2, MX3, MX4, MX5, MX6, MX7, MX8, MX9, MX10, MX17, MX18, MX19, MX20, MX21, MX22, MX23, MX24, MX25, MX26, MX27, MX28, MX29, MX30, MX31, MX32, MX33, MX35, MX36, MX37, MX38, MX39, MX40, MX41, MX42, MX43, MX44, MX45, MX46, MX48, MX49, MX50, MX53, MX54, MX55, MX56, MX57, MX58, MX59, MX60, MX61, MX62, MX63, MX64, MX65, MX66, MX67, MX68, MX69, MX70, MX71, MX72, MX73, MX74, MX75, MX76, MX77, MX81, MX86, MX87, MX88, MX90, MX92, MX94: MX_SW_HS; SW_MX_HS_1u
MX34, MX47, MX89, MX91, MX93, MX95: MX_SW_HS; SW_MX_HS_1.5u
MX51: MX_SW_HS; SW_MX_HS_1.75u_STP_1.25
MX52: MX_SW_HS; SW_MX_HS_1.75u
MX78, MX79, MX80, MX82, MX83, MX84, MX85: MX_SW_HS; SW_MX_HS_1.25u
R1, R2: 27; R_0402_1005Metric
R3, R7: 1k; R_0402_1005Metric
R4, R5, R6, R8, R9, R10, R11: 5.1k; R_0402_1005Metric
RESET1: SW_Push; PinSocket_1x02_P2.54mm_Vertical
S1: stb; STAB_MX_P_2u
S3, S4: stb; STAB_MX_P_2.25u
S5: stb; STAB_MX_P_2.75u
S6: stb; STAB_MX_P_7u
S7: stb; STAB_MX_P_6.25u
U1: RP2040; QFN-56-1EP_7x7mm_P0.4mm_EP3.2x3.2mm
U2: XC6206P332MR; SOT-23-3
U3: W25Q128JVSIQ; SOIC-8_5.23x5.23mm_P1.27mm
U4, U5: SRV05-4; SOT-23-6-routable
Y1: X322512MSB4SI; Crystal_SMD_3225-4Pin_3.2x2.5mm

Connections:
+1V1: C1.1, C2.1, C3.1, U1.23 (DVDD), U1.45 (VREG_VOUT), U1.50 (DVDD)
+3V3: C4.1, C5.1, C6.1, C7.1, C8.1, C9.1, C10.1, C11.1, C13.1, C14.1, J3.1, J8.1, R4.2, R5.2, U1.1 (IOVDD), U1.10 (IOVDD), U1.22 (IOVDD), U1.33 (IOVDD), U1.42 (IOVDD), U1.43 (ADC_AVDD), U1.44 (VREG_IN), U1.48 (USB_VDD), U1.49 (IOVDD), U2.2 (VO), U3.8 (VCC)
+5V: C12.1, F1.1, J1.1, U2.3 (VI), U4.5 (VP)
+5VA: F2.1, J4.4, U5.5 (VP)
COL0: MX1.1, MX3.1, MX5.1, MX7.1, MX9.1, U1.11 (GPIO8)
COL1: MX2.1, MX4.1, MX6.1, MX8.1, MX10.1, U1.12 (GPIO9)
COL2: MX17.1, MX34.1, MX51.1, MX52.2, MX65.1, MX78.1, MX89.2, U1.18 (GPIO15)
COL3: MX18.1, MX35.1, U1.31 (GPIO20)
COL4: MX19.1, MX36.1, MX53.1, MX66.1, MX79.1, MX90.2, U1.30 (GPIO19)
COL5: MX20.1, MX37.1, MX54.1, MX67.1, MX80.1, MX91.2, U1.29 (GPIO18)
COL6: MX21.1, MX38.1, MX55.1, MX68.1, U1.28 (GPIO17)
COL7: MX22.1, MX39.1, MX56.1, MX69.1, U1.27 (GPIO16)
COL8: MX23.1, MX40.1, MX57.1, MX70.1, MX81.1, MX92.2, U1.41 (GPIO29_ADC3)
COL9: MX24.1, MX41.1, MX58.1, MX71.1, U1.40 (GPIO28_ADC2)
COL10: MX25.1, MX42.1, MX59.1, MX72.1, U1.39 (GPIO27_ADC1)
COL11: MX26.1, MX43.1, MX60.1, MX73.1, U1.38 (GPIO26_ADC0)
COL12: MX27.1, MX44.1, MX61.1, MX74.1, MX82.1, U1.37 (GPIO25)
COL13: MX28.1, MX45.1, MX62.1, MX75.1, MX83.2, MX93.1, U1.36 (GPIO24)
COL14: MX29.1, MX46.1, MX63.1, MX84.2, MX94.1, U1.35 (GPIO23)
COL15: MX30.1, MX47.1, MX64.1, MX76.1, MX85.2, MX95.1, U1.34 (GPIO22)
COL16: MX31.1, MX48.1, MX86.1, U1.15 (GPIO12)
COL17: MX32.1, MX49.1, MX77.1, MX87.1, U1.14 (GPIO11)
COL18: MX33.1, MX50.1, MX88.1, U1.13 (GPIO10)
GND: BOOT1.1, C1.2, C2.2, C3.2, C4.2, C5.2, C6.2, C7.2, C8.2, C9.2, C10.2, C11.2, C12.2, C13.2, C14.2, C15.1, C16.1, J1.4, J2.A1 (GND), J2.A12 (GND), J2.B1 (GND), J2.B12 (GND), J2.S1 (SHIELD), J8.2, R8.2, R9.2, RESET1.1, U1.19 (TESTEN), U1.57 (GND), U2.1 (GND), U3.4 (GND), U4.2 (VN), Y1.2, Y1.4
GNDA: J4.1, J5.A1 (GND), J5.A12 (GND), J5.B1 (GND), J5.B12 (GND), J5.S1 (SHIELD), R10.2, R11.2, U5.2 (VN)
GP_SCL: J8.4, U1.7 (GPIO5)
GP_SDA: J8.3, U1.8 (GPIO6)
unnamed: BOOT1.2, R7.1
unnamed: C16.2, R3.1, Y1.1
unnamed: D1.2 (A), MX1.2
unnamed: D2.2 (A), MX2.2
unnamed: D3.2 (A), MX3.2
unnamed: D4.2 (A), MX4.2
unnamed: D5.2 (A), MX5.2
unnamed: D6.2 (A), MX6.2
unnamed: D7.2 (A), MX7.2
unnamed: D8.2 (A), MX8.2
unnamed: D9.2 (A), MX9.2
unnamed: D10.2 (A), MX10.2
unnamed: D17.2 (A), MX17.2
unnamed: D18.2 (A), MX18.2
unnamed: D19.2 (A), MX19.2
unnamed: D20.2 (A), MX20.2
unnamed: D21.2 (A), MX21.2
unnamed: D22.2 (A), MX22.2
unnamed: D23.2 (A), MX23.2
unnamed: D24.2 (A), MX24.2
unnamed: D25.2 (A), MX25.2
unnamed: D26.2 (A), MX26.2
unnamed: D27.2 (A), MX27.2
unnamed: D28.2 (A), MX28.2
unnamed: D29.2 (A), MX29.2
unnamed: D30.2 (A), MX30.2
unnamed: D31.2 (A), MX31.2
unnamed: D32.2 (A), MX32.2
unnamed: D33.2 (A), MX33.2
unnamed: D34.2 (A), MX34.2
unnamed: D35.2 (A), MX35.2
unnamed: D36.2 (A), MX36.2
unnamed: D37.2 (A), MX37.2
unnamed: D38.2 (A), MX38.2
unnamed: D39.2 (A), MX39.2
unnamed: D40.2 (A), MX40.2
unnamed: D41.2 (A), MX41.2
unnamed: D42.2 (A), MX42.2
unnamed: D43.2 (A), MX43.2
unnamed: D44.2 (A), MX44.2
unnamed: D45.2 (A), MX45.2
unnamed: D46.2 (A), MX46.2
unnamed: D47.2 (A), MX47.2
unnamed: D48.2 (A), MX48.2
unnamed: D49.2 (A), MX49.2
unnamed: D50.2 (A), MX50.2
unnamed: D51.2 (A), MX51.2, MX52.1
unnamed: D53.2 (A), MX53.2
unnamed: D54.2 (A), MX54.2
unnamed: D55.2 (A), MX55.2
unnamed: D56.2 (A), MX56.2
unnamed: D57.2 (A), MX57.2
unnamed: D58.2 (A), MX58.2
unnamed: D59.2 (A), MX59.2
unnamed: D60.2 (A), MX60.2
unnamed: D61.2 (A), MX61.2
unnamed: D62.2 (A), MX62.2
unnamed: D63.2 (A), MX63.2
unnamed: D64.2 (A), MX64.2
unnamed: D65.2 (A), MX65.2
unnamed: D66.2 (A), MX66.2
unnamed: D67.2 (A), MX67.2
unnamed: D68.2 (A), MX68.2
unnamed: D69.2 (A), MX69.2
unnamed: D70.2 (A), MX70.2
unnamed: D71.2 (A), MX71.2
unnamed: D72.2 (A), MX72.2
unnamed: D73.2 (A), MX73.2
unnamed: D74.2 (A), MX74.2
unnamed: D75.2 (A), MX75.2
unnamed: D76.2 (A), MX76.2
unnamed: D77.2 (A), MX77.2
unnamed: D78.2 (A), MX78.2, MX89.1
unnamed: D79.2 (A), MX79.2, MX90.1
unnamed: D80.2 (A), MX80.2, MX91.1
unnamed: D81.2 (A), MX81.2, MX92.1
unnamed: D82.2 (A), MX82.2
unnamed: D83.2 (A), MX83.1, MX93.2
unnamed: D84.2 (A), MX84.1, MX94.2
unnamed: D85.2 (A), MX85.1, MX95.2
unnamed: D86.2 (A), MX86.2
unnamed: D87.2 (A), MX87.2
unnamed: D88.2 (A), MX88.2
unnamed: J2.A5 (CC1), R8.1
unnamed: J2.B5 (CC2), R9.1
unnamed: J5.A5 (CC1), R10.1
unnamed: J5.B5 (CC2), R11.1
unnamed: R4.1, R6.2
unnamed: R2.2, U1.46 (USB_DM)
unnamed: R1.2, U1.47 (USB_DP)
QSPI_SCLK: U1.52 (QSPI_SCLK), U3.6 (CLK)
QSPI_SD0: U1.53 (QSPI_SD0), U3.5 (DI(IO0))
QSPI_SD1: U1.55 (QSPI_SD1), U3.2 (DO(IO1))
QSPI_SD2: U1.54 (QSPI_SD2), U3.3 (IO2)
QSPI_SD3: U1.51 (QSPI_SD3), U3.7 (IO3)
QSPI_SS: R6.1, R7.2, U1.56 (QSPI_SS), U3.1 (~CS)
RESET: R5.1, RESET1.2, U1.26 (RUN)
ROW0: D1.1 (K), D2.1 (K), D17.1 (K), D18.1 (K), D19.1 (K), D20.1 (K), D21.1 (K), D22.1 (K), D23.1 (K), D24.1 (K), D25.1 (K), D26.1 (K), D27.1 (K), D28.1 (K), D29.1 (K), D30.1 (K), D31.1 (K), D32.1 (K), D33.1 (K), U1.3 (GPIO1)
ROW1: D3.1 (K), D4.1 (K), D34.1 (K), D35.1 (K), D36.1 (K), D37.1 (K), D38.1 (K), D39.1 (K), D40.1 (K), D41.1 (K), D42.1 (K), D43.1 (K), D44.1 (K), D45.1 (K), D46.1 (K), D47.1 (K), D48.1 (K), D49.1 (K), D50.1 (K), U1.2 (GPIO0)
ROW2: D5.1 (K), D6.1 (K), D51.1 (K), D53.1 (K), D54.1 (K), D55.1 (K), D56.1 (K), D57.1 (K), D58.1 (K), D59.1 (K), D60.1 (K), D61.1 (K), D62.1 (K), D63.1 (K), D64.1 (K), U1.32 (GPIO21)
ROW3: D7.1 (K), D8.1 (K), D65.1 (K), D66.1 (K), D67.1 (K), D68.1 (K), D69.1 (K), D70.1 (K), D71.1 (K), D72.1 (K), D73.1 (K), D74.1 (K), D75.1 (K), D76.1 (K), D77.1 (K), U1.16 (GPIO13)
ROW4: D9.1 (K), D10.1 (K), D78.1 (K), D79.1 (K), D80.1 (K), D81.1 (K), D82.1 (K), D83.1 (K), D84.1 (K), D85.1 (K), D86.1 (K), D87.1 (K), D88.1 (K), U1.17 (GPIO14)
SW: J8.5, U1.6 (GPIO4)
SWCLK: J3.2, U1.24 (SWCLK)
SWD: J3.3, U1.25 (SWD)
USB_D+: J1.3, J2.A6 (D+), J2.B6 (D+), R1.1, U4.1 (IO1)
USB_D+_DB: J4.2, J5.A6 (D+), J5.B6 (D+), U5.1 (IO1)
USB_D-: J1.2, J2.A7 (D-), J2.B7 (D-), R2.1, U4.6 (IO4)
USB_D-_DB: J4.3, J5.A7 (D-), J5.B7 (D-), U5.6 (IO4)
VBUS: F1.2, J2.A4 (VBUS), J2.A9 (VBUS), J2.B4 (VBUS), J2.B9 (VBUS)
VCC: F2.2, J5.A4 (VBUS), J5.A9 (VBUS), J5.B4 (VBUS), J5.B9 (VBUS)
XIN: C15.2, U1.20 (XIN), Y1.3
XOUT: R3.2, U1.21 (XOUT)

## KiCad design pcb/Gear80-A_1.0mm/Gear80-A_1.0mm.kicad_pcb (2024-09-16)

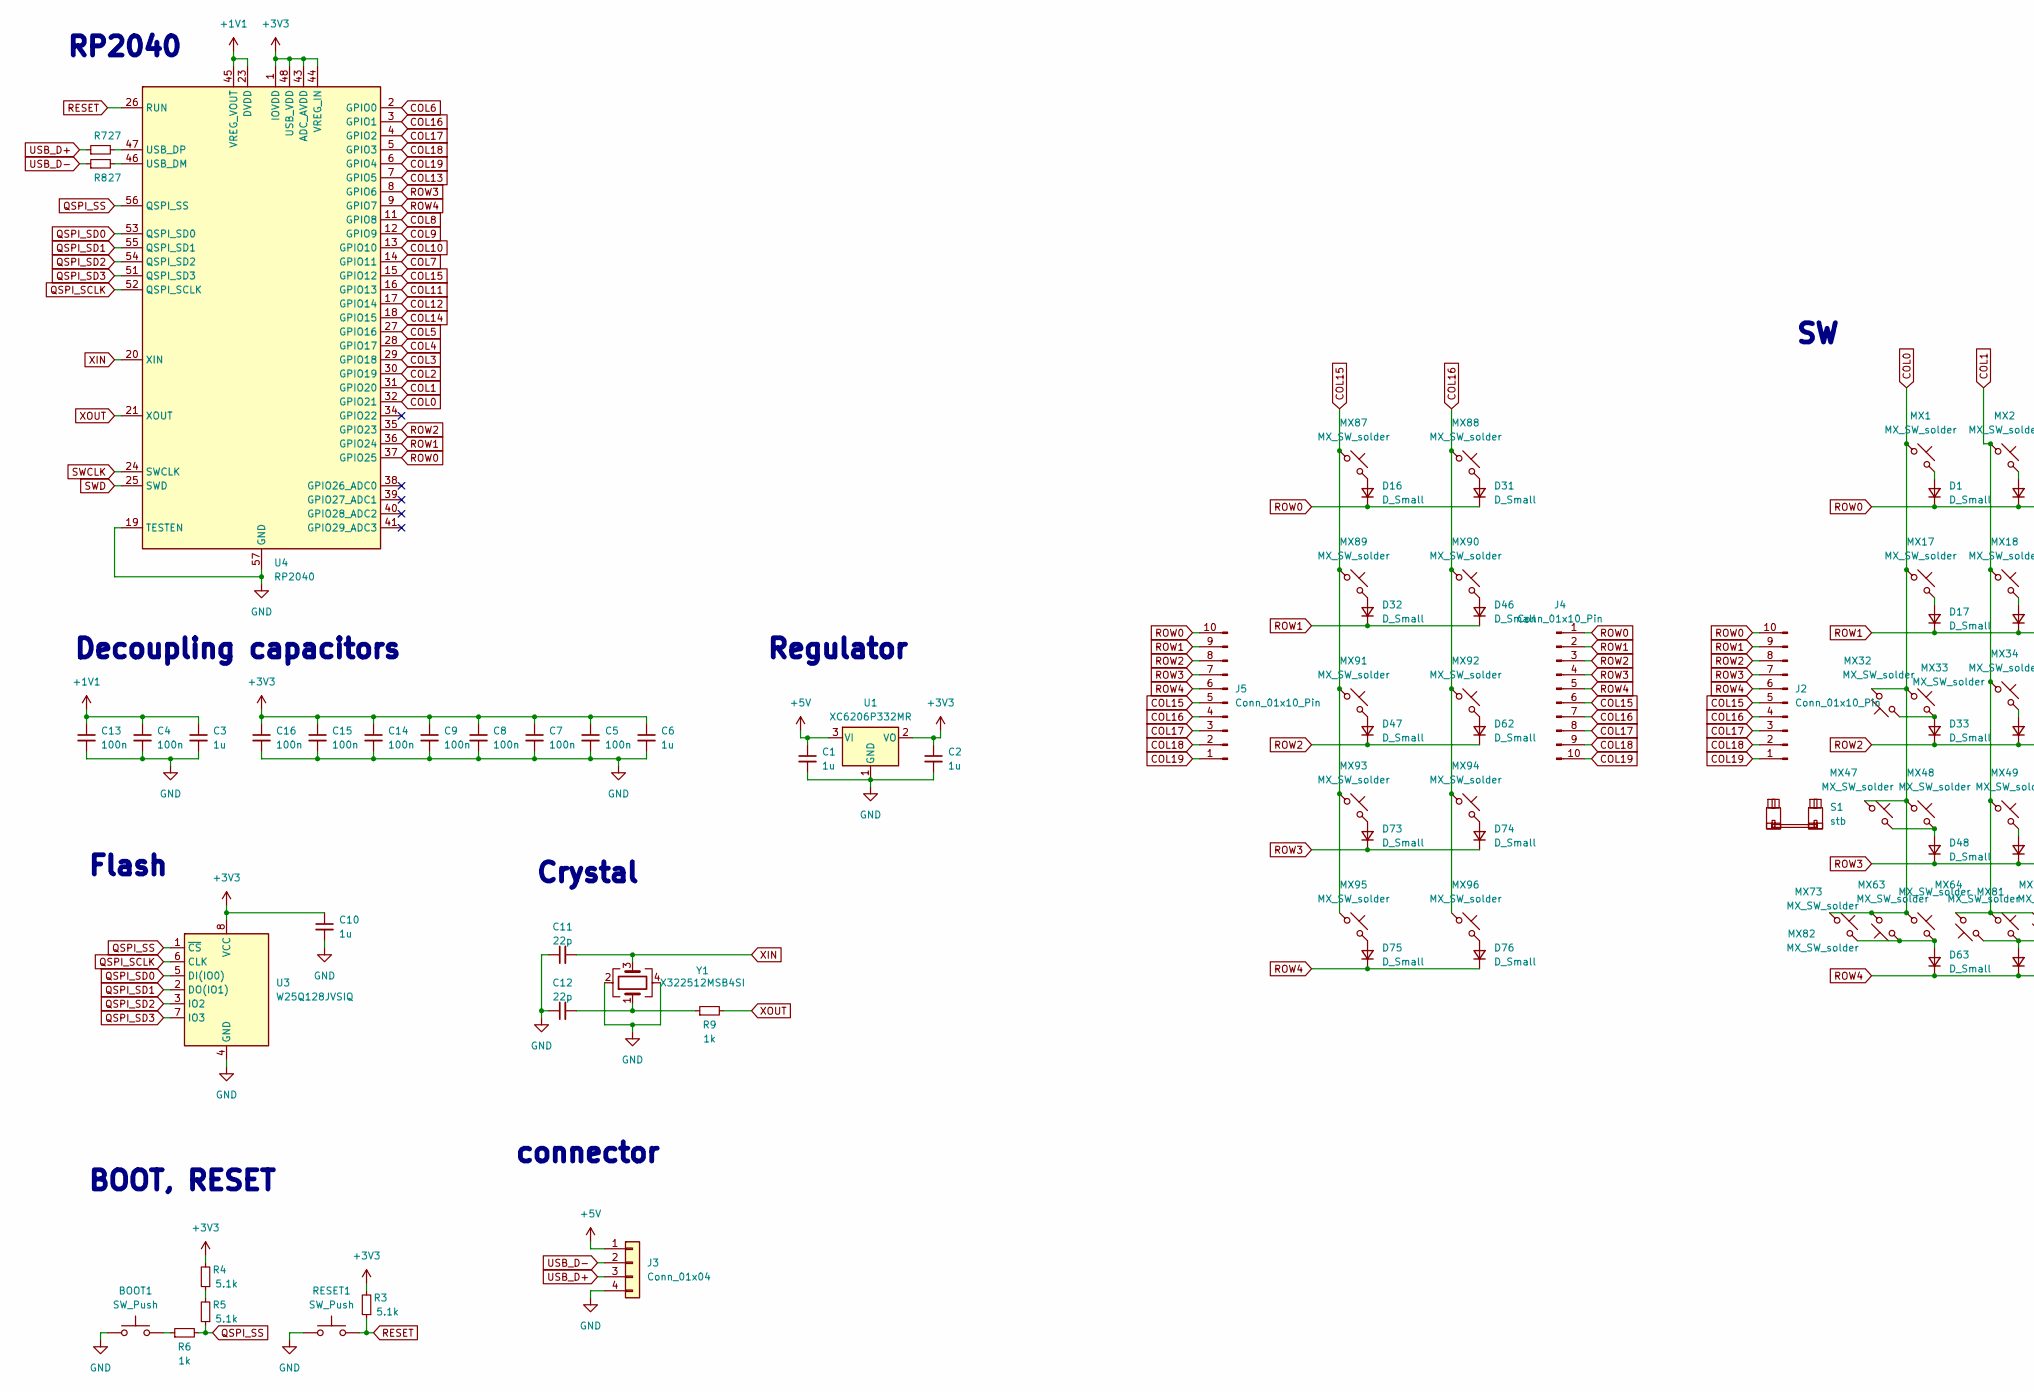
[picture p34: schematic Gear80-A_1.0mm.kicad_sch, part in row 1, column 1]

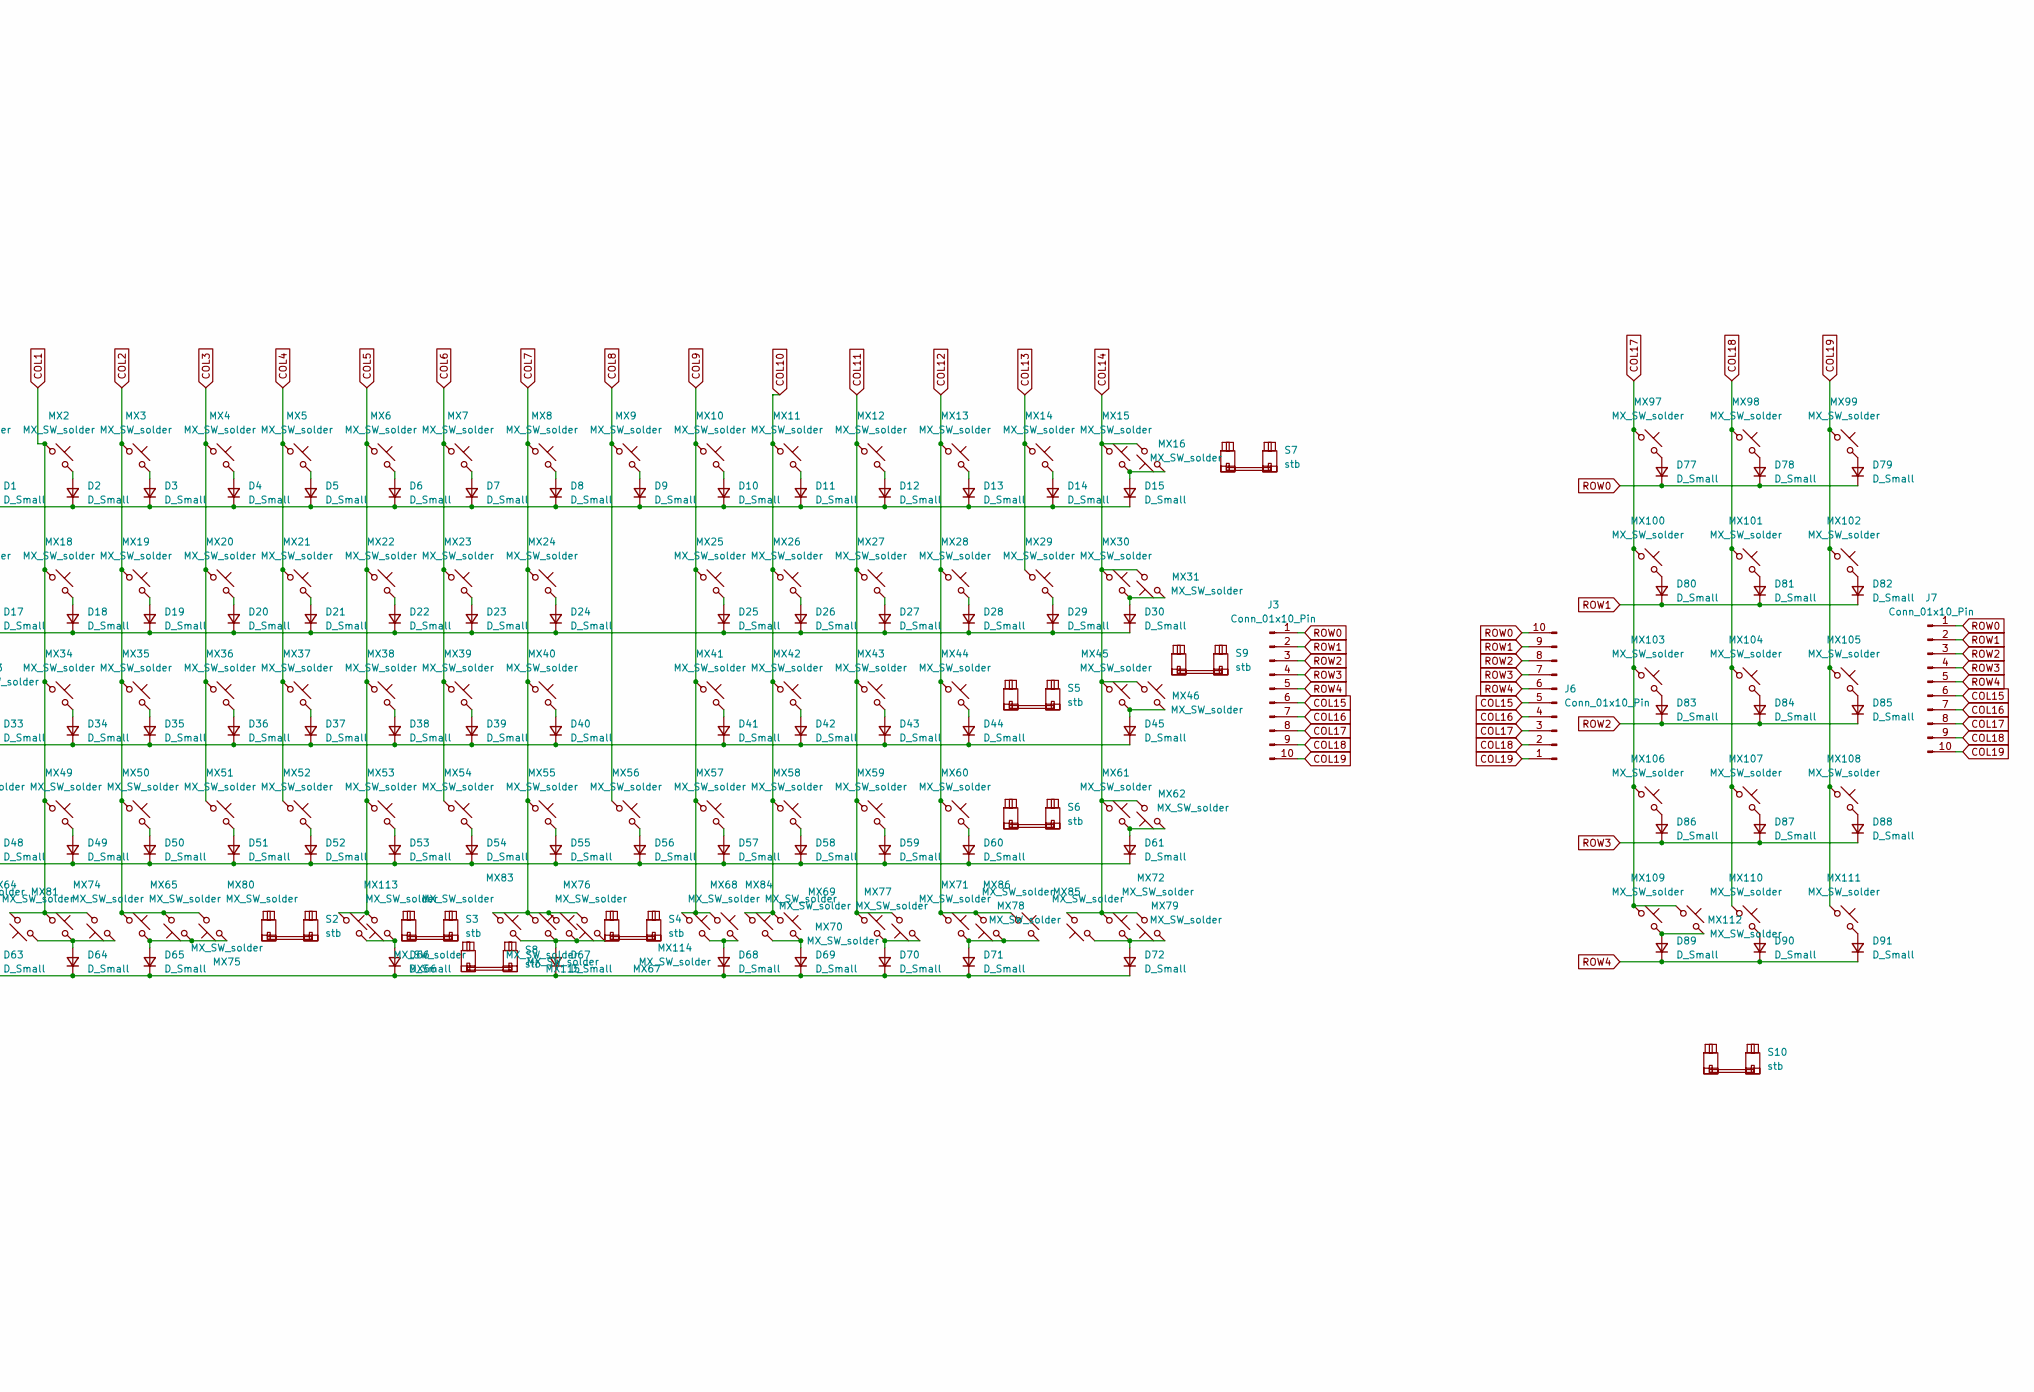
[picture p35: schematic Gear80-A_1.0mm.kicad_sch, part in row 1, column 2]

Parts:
BOOT1: SW_Push; PinSocket_1x02_P2.54mm_Vertical
C1, C2, C3, C6, C10: 1u; C_0402_1005Metric
C4, C5, C7, C8, C9, C13, C14, C15, C16: 100n; C_0402_1005Metric
C11, C12: 22p; C_0402_1005Metric
D1, D2, D3, D4, D5, D6, D7, D8, D9, D10, D11, D12, D13, D14, D15, D16, D17, D18, D19, D20, D21, D22, D23, D24, D25, D26, D27, D28, D29, D30, D31, D32, D33, D34, D35, D36, D37, D38, D39, D40, D41, D42, D43, D44, D45, D46, D47, D48, D49, D50, D51, D52, D53, D54, D55, D56, D57, D58, D59, D60, D61, D62, D63, D64, D65, D66, D67, D68, D69, D70, D71, D72, D73, D74, D75, D76, D77, D78, D79, D80, D81, D82, D83, D84, D85, D86, D87, D88, D89, D90, D91: D_Small; D_SOD-123
J2, J3, J4, J5, J6, J7: Conn_01x10_Pin; Molex_200528-0100_1x10-1MP_P1.00mm_Horizontal
MX1, MX2, MX3, MX4, MX5, MX6, MX7, MX8, MX9, MX10, MX11, MX12, MX13, MX14, MX15, MX16, MX18, MX19, MX20, MX21, MX22, MX23, MX24, MX25, MX26, MX27, MX28, MX29, MX31, MX34, MX35, MX36, MX37, MX38, MX39, MX40, MX41, MX42, MX43, MX44, MX45, MX46, MX47, MX49, MX50, MX51, MX52, MX53, MX54, MX55, MX56, MX57, MX58, MX59, MX61, MX62, MX63, MX64, MX66, MX67, MX69, MX70, MX71, MX72, MX74, MX76, MX78, MX83, MX87, MX88, MX89, MX90, MX91, MX92, MX93, MX94, MX95, MX96, MX97, MX98, MX99, MX100, MX101, MX102, MX103, MX104, MX105, MX106, MX107, MX108, MX109, MX110, MX111, MX112, MX113, MX114, MX115: MX_SW_solder; SW_MX_1u
MX17, MX30, MX73, MX75, MX79: MX_SW_solder; SW_MX_1.5u
MX32: MX_SW_solder; SW_MX_1.75u_STP_1.25
MX33, MX60: MX_SW_solder; SW_MX_1.75u
MX48, MX65, MX68, MX77, MX80, MX81, MX82, MX84, MX85, MX86: MX_SW_solder; SW_MX_1.25u
R3, R4, R5: 5.1k; R_0402_1005Metric
R6, R9: 1k; R_0402_1005Metric
R7, R8: 27; R_0402_1005Metric
RESET1: SW_Push; PinSocket_1x02_P2.54mm_Vertical
S1, S3, S5: stb; STAB_MX_P_2.25u
S2, S6: stb; STAB_MX_P_2.75u
S4: stb; STAB_MX_P_7u
S7, S10: stb; STAB_MX_P_2u
S8: stb; STAB_MX_P_6.25u
S9: stb; STAB_MX_ISO
U1: XC6206P332MR; SOT-23-3
U3: W25Q128JVSIQ; SOIC-8_5.23x5.23mm_P1.27mm
U4: RP2040; QFN-56-1EP_7x7mm_P0.4mm_EP3.2x3.2mm
Y1: X322512MSB4SI; Crystal_SMD_3225-4Pin_3.2x2.5mm

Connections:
+1V1: C3.1, C4.1, C13.1, U4.23 (DVDD), U4.45 (VREG_VOUT), U4.50 (DVDD)
+3V3: C2.1, C5.1, C6.1, C7.1, C8.1, C9.1, C10.1, C14.1, C15.1, C16.1, R3.2, R4.2, U1.2 (VO), U3.8 (VCC), U4.1 (IOVDD), U4.10 (IOVDD), U4.22 (IOVDD), U4.33 (IOVDD), U4.42 (IOVDD), U4.43 (ADC_AVDD), U4.44 (VREG_IN), U4.48 (USB_VDD), U4.49 (IOVDD)
COL0: MX1.1, MX17.1, MX32.2, MX33.1, MX47.1, MX48.1, MX63.1, MX73.2, MX82.1, U4.32 (GPIO21)
COL1: MX2.1, MX18.1, MX34.1, MX49.1, MX64.1, MX74.2, MX81.2, U4.31 (GPIO20)
COL2: MX3.1, MX19.1, MX35.1, MX50.1, MX65.1, MX75.2, MX80.2, U4.30 (GPIO19)
COL3: MX4.1, MX20.1, MX36.1, MX51.1, U4.29 (GPIO18)
COL4: MX5.1, MX21.1, MX37.1, MX52.1, U4.28 (GPIO17)
COL5: MX6.1, MX22.1, MX38.1, MX53.1, MX66.2, MX113.1, U4.27 (GPIO16)
COL6: MX7.1, MX23.1, MX39.1, MX54.1, U4.2 (GPIO0)
COL7: MX8.1, MX24.1, MX40.1, MX55.1, MX67.1, MX76.1, MX83.1, MX115.2, U4.14 (GPIO11)
COL8: MX9.1, MX56.1, U4.11 (GPIO8)
COL9: MX10.1, MX25.1, MX41.1, MX57.1, MX68.1, MX114.1, U4.12 (GPIO9)
COL10: MX11.1, MX26.1, MX42.1, MX58.1, MX69.1, MX84.1, U4.13 (GPIO10)
COL11: MX12.1, MX27.1, MX43.1, MX59.1, MX70.1, MX77.2, U4.16 (GPIO13)
COL12: MX13.1, MX28.1, MX44.1, MX60.1, MX71.1, MX78.2, MX86.1, U4.17 (GPIO14)
COL13: MX14.1, MX29.1, U4.7 (GPIO5)
COL14: MX15.1, MX16.2, MX30.1, MX31.2, MX45.1, MX46.1, MX61.1, MX62.2, MX72.1, MX79.2, MX85.2, U4.18 (GPIO15)
COL15: J2.5, J3.6, J4.6, J5.5, J6.5, J7.6, MX87.1, MX89.1, MX91.1, MX93.1, MX95.1, U4.15 (GPIO12)
COL16: J2.4, J3.7, J4.7, J5.4, J6.4, J7.7, MX88.1, MX90.1, MX92.1, MX94.1, MX96.1, U4.3 (GPIO1)
COL17: J2.3, J3.8, J4.8, J5.3, J6.3, J7.8, MX97.1, MX100.1, MX103.1, MX106.1, MX109.1, MX112.1, U4.4 (GPIO2)
COL18: J2.2, J3.9, J4.9, J5.2, J6.2, J7.9, MX98.1, MX101.1, MX104.1, MX107.1, MX110.1, U4.5 (GPIO3)
COL19: J2.1, J3.10, J4.10, J5.1, J6.1, J7.10, MX99.1, MX102.1, MX105.1, MX108.1, MX111.1, U4.6 (GPIO4)
unnamed: BOOT1.2, R6.1
unnamed: C12.2, R9.1, Y1.1
unnamed: D1.2 (A), MX1.2
unnamed: D2.2 (A), MX2.2
unnamed: D3.2 (A), MX3.2
unnamed: D4.2 (A), MX4.2
unnamed: D5.2 (A), MX5.2
unnamed: D6.2 (A), MX6.2
unnamed: D7.2 (A), MX7.2
unnamed: D8.2 (A), MX8.2
unnamed: D9.2 (A), MX9.2
unnamed: D10.2 (A), MX10.2
unnamed: D11.2 (A), MX11.2
unnamed: D12.2 (A), MX12.2
unnamed: D13.2 (A), MX13.2
unnamed: D14.2 (A), MX14.2
unnamed: D15.2 (A), MX15.2, MX16.1
unnamed: D16.2 (A), MX87.2
unnamed: D17.2 (A), MX17.2
unnamed: D18.2 (A), MX18.2
unnamed: D19.2 (A), MX19.2
unnamed: D20.2 (A), MX20.2
unnamed: D21.2 (A), MX21.2
unnamed: D22.2 (A), MX22.2
unnamed: D23.2 (A), MX23.2
unnamed: D24.2 (A), MX24.2
unnamed: D25.2 (A), MX25.2
unnamed: D26.2 (A), MX26.2
unnamed: D27.2 (A), MX27.2
unnamed: D28.2 (A), MX28.2
unnamed: D29.2 (A), MX29.2
unnamed: D30.2 (A), MX30.2, MX31.1
unnamed: D31.2 (A), MX88.2
unnamed: D32.2 (A), MX89.2
unnamed: D33.2 (A), MX32.1, MX33.2
unnamed: D34.2 (A), MX34.2
unnamed: D35.2 (A), MX35.2
unnamed: D36.2 (A), MX36.2
unnamed: D37.2 (A), MX37.2
unnamed: D38.2 (A), MX38.2
unnamed: D39.2 (A), MX39.2
unnamed: D40.2 (A), MX40.2
unnamed: D41.2 (A), MX41.2
unnamed: D42.2 (A), MX42.2
unnamed: D43.2 (A), MX43.2
unnamed: D44.2 (A), MX44.2
unnamed: D45.2 (A), MX45.2, MX46.2
unnamed: D46.2 (A), MX90.2
unnamed: D47.2 (A), MX91.2
unnamed: D48.2 (A), MX47.2, MX48.2
unnamed: D49.2 (A), MX49.2
unnamed: D50.2 (A), MX50.2
unnamed: D51.2 (A), MX51.2
unnamed: D52.2 (A), MX52.2
unnamed: D53.2 (A), MX53.2
unnamed: D54.2 (A), MX54.2
unnamed: D55.2 (A), MX55.2
unnamed: D56.2 (A), MX56.2
unnamed: D57.2 (A), MX57.2
unnamed: D58.2 (A), MX58.2
unnamed: D59.2 (A), MX59.2
unnamed: D60.2 (A), MX60.2
unnamed: D61.2 (A), MX61.2, MX62.1
unnamed: D62.2 (A), MX92.2
unnamed: D63.2 (A), MX63.2, MX73.1, MX82.2
unnamed: D64.2 (A), MX64.2, MX74.1, MX81.1
unnamed: D65.2 (A), MX65.2, MX75.1, MX80.1
unnamed: D66.2 (A), MX66.1, MX113.2
unnamed: D67.2 (A), MX67.2, MX76.2, MX83.2, MX115.1
unnamed: D68.2 (A), MX68.2, MX114.2
unnamed: D69.2 (A), MX69.2, MX84.2
unnamed: D70.2 (A), MX70.2, MX77.1
unnamed: D71.2 (A), MX71.2, MX78.1, MX86.2
unnamed: D72.2 (A), MX72.2, MX79.1, MX85.1
unnamed: D73.2 (A), MX93.2
unnamed: D74.2 (A), MX94.2
unnamed: D75.2 (A), MX95.2
unnamed: D76.2 (A), MX96.2
unnamed: D77.2 (A), MX97.2
unnamed: D78.2 (A), MX98.2
unnamed: D79.2 (A), MX99.2
unnamed: D80.2 (A), MX100.2
unnamed: D81.2 (A), MX101.2
unnamed: D82.2 (A), MX102.2
unnamed: D83.2 (A), MX103.2
unnamed: D84.2 (A), MX104.2
unnamed: D85.2 (A), MX105.2
unnamed: D86.2 (A), MX106.2
unnamed: D87.2 (A), MX107.2
unnamed: D88.2 (A), MX108.2
unnamed: D89.2 (A), MX109.2, MX112.2
unnamed: D90.2 (A), MX110.2
unnamed: D91.2 (A), MX111.2
unnamed: R4.1, R5.2
unnamed: R8.2, U4.46 (USB_DM)
unnamed: R7.2, U4.47 (USB_DP)
QSPI_SCLK: U3.6 (CLK), U4.52 (QSPI_SCLK)
QSPI_SD0: U3.5 (DI(IO0)), U4.53 (QSPI_SD0)
QSPI_SD1: U3.2 (DO(IO1)), U4.55 (QSPI_SD1)
QSPI_SD2: U3.3 (IO2), U4.54 (QSPI_SD2)
QSPI_SD3: U3.7 (IO3), U4.51 (QSPI_SD3)
QSPI_SS: R5.1, R6.2, U3.1 (~CS), U4.56 (QSPI_SS)
RESET: R3.1, RESET1.2, U4.26 (RUN)
ROW4: D63.1 (K), D64.1 (K), D65.1 (K), D66.1 (K), D67.1 (K), D68.1 (K), D69.1 (K), D70.1 (K), D71.1 (K), D72.1 (K), D75.1 (K), D76.1 (K), D89.1 (K), D90.1 (K), D91.1 (K), J2.6, J3.5, J4.5, J5.6, J6.6, J7.5, U4.9 (GPIO7)
SWCLK: U4.24 (SWCLK)
SWD: U4.25 (SWD)
XIN: C11.2, U4.20 (XIN), Y1.3
XOUT: R9.2, U4.21 (XOUT)

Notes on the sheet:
BOOT, RESET
Decoupling capacitors
RP2040
connector
Crystal
Regulator
Flash

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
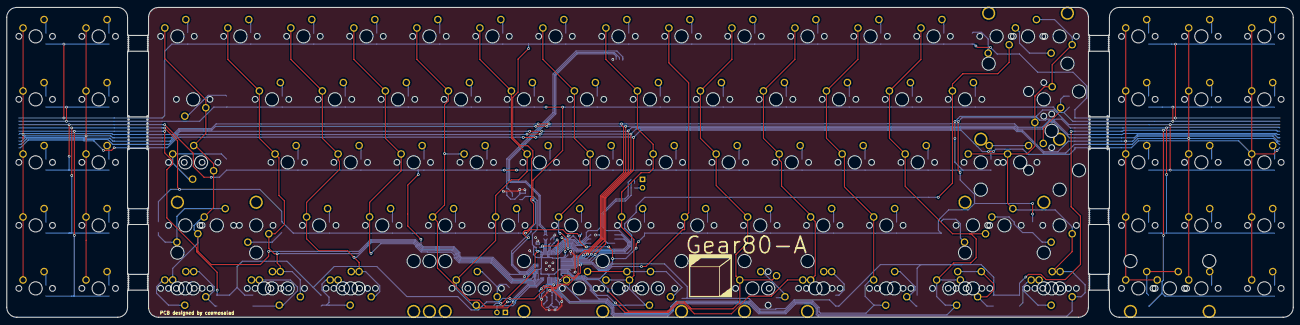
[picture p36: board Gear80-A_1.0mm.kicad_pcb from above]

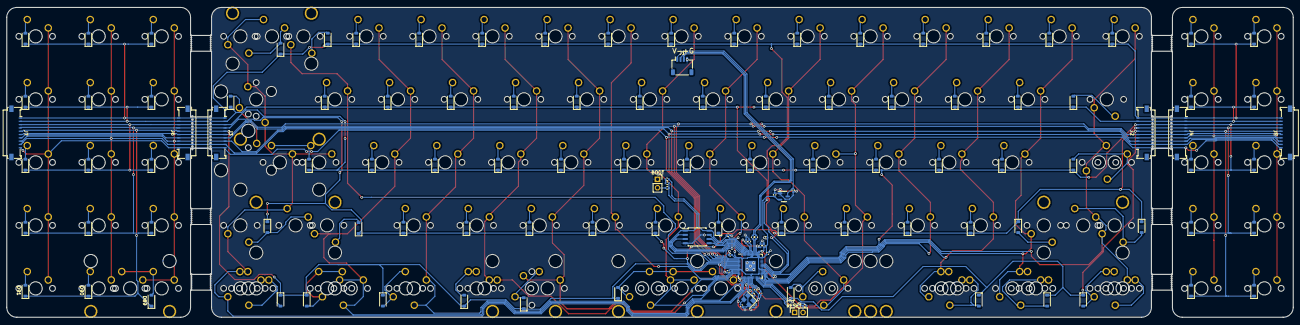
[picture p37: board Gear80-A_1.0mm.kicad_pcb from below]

Board: 2 copper layers, 388.9 x 93.7 mm, 252 parts (127 on the bottom side), 136 nets.

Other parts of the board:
J1: Conn_01x04; JST_SH_SM04B-SRSS-TB_1x04-1MP_P1.00mm_Horizontal

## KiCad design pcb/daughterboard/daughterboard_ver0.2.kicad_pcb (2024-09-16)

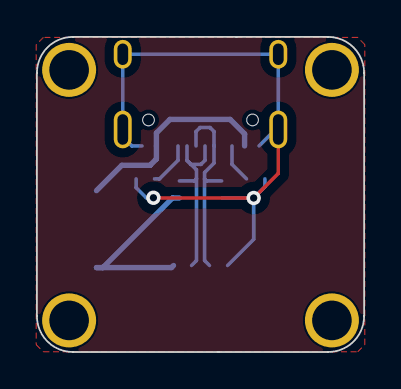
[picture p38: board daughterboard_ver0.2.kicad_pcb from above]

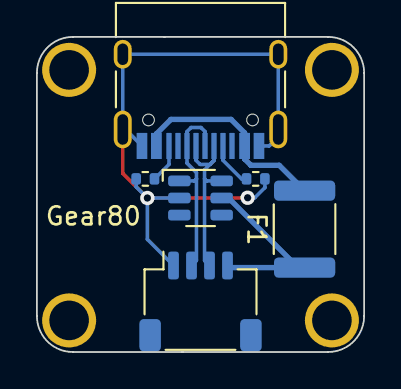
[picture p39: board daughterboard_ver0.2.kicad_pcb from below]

Board: 2 copper layers, 18.2 x 17.5 mm, 6 parts (6 on the bottom side), 7 nets.

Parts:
F1: MF-MSMF050-2; Fuse_1812_4532Metric
J1: Conn_01x04; JST_SH_SM04B-SRSS-TB_1x04-1MP_P1.00mm_Horizontal
J2: USB_C_Receptacle_USB2.0; USB_C_Receptacle_HRO_TYPE-C-31-M-12
R1, R2: 5.1k; R_0402_1005Metric
U1: SRV05-4; SOT-23-6-routable

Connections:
+5V: F1.1, J1.4, U1.5 (VP)
GND: J1.1, J2.A1 (GND), J2.A12 (GND), J2.B1 (GND), J2.B12 (GND), J2.S1 (SHIELD), R1.2, R2.2, U1.2 (VN)
unnamed: J2.A5 (CC1), R1.1
unnamed: J2.B5 (CC2), R2.1
USB_D+: J1.2, J2.A6 (D+), J2.B6 (D+), U1.1 (IO1)
USB_D-: J1.3, J2.A7 (D-), J2.B7 (D-), U1.6 (IO4)
VBUS: F1.2, J2.A4 (VBUS), J2.A9 (VBUS), J2.B4 (VBUS), J2.B9 (VBUS)

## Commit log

2024-03-09 Create Gear80_hotswap
2024-03-09 Create Gear80_solder
2024-07-16 Update and rename daughterboard.kicad_pcb to daughterboard.kicad_pcb_ver0.1
2024-07-16 Update and rename daughterboard.kicad_sch to daughterboard_ver.0.1.kicad_sch
    [daughterboard_ver.0.1.kicad_sch]
2024-07-16 Update and rename daughterboard.kicad_pcb_ver0.1 to daughterboard_ver0.1.kicad_pcb
    [daughterboard_ver0.1.kicad_pcb]
2024-07-16 Update and rename daughterboard_ver.0.1.kicad_sch to daughterboard_ver0.1.kicad_sch
    [daughterboard_ver0.1.kicad_sch]
